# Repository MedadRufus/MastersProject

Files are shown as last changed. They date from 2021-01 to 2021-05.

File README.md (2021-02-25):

# MastersProject
 
# Requirements
Design a data logger for E bikes that can record:

It needs to 
* measure: battery current for output and charging(1mA precision), voltage(10mV precision), inclination of road, humidity(as proxy for rain), tempreature of battery, external temperature, e-bike velocity, accleration.
* run off the battery pack
* consume minimal power
* be sturdy enough to survive near the battery pack
* Measure the environmental values(temperature, humidity) without being affected by the system(e.g. heat from the battery)
* measure at least 2 weeks of non stop data
* option to auto upload to the cloud, when connected to wifi.
* cloud dashboard
* log data at max data rate of 1 sample per second
* Needs to handle significant noise in power supply generated by Motor
* Need to handle inductive currents from motor
* Needs isolation from motor.

The idea is to see how estimate battery discharge profiles to do accurate range and state of charge estimations.

Hardware ideas:
* Accleration/tilt from LSM9DS1. Tilt can be measured from sensor fusino on the mcu
* Processor: ESP32
* Current sensor: INA226, 500 kHz +/- 30% sample rate. Up to 36V.
* GPS: Ublox with antenna

# Overall System diagram


# Basic physical design
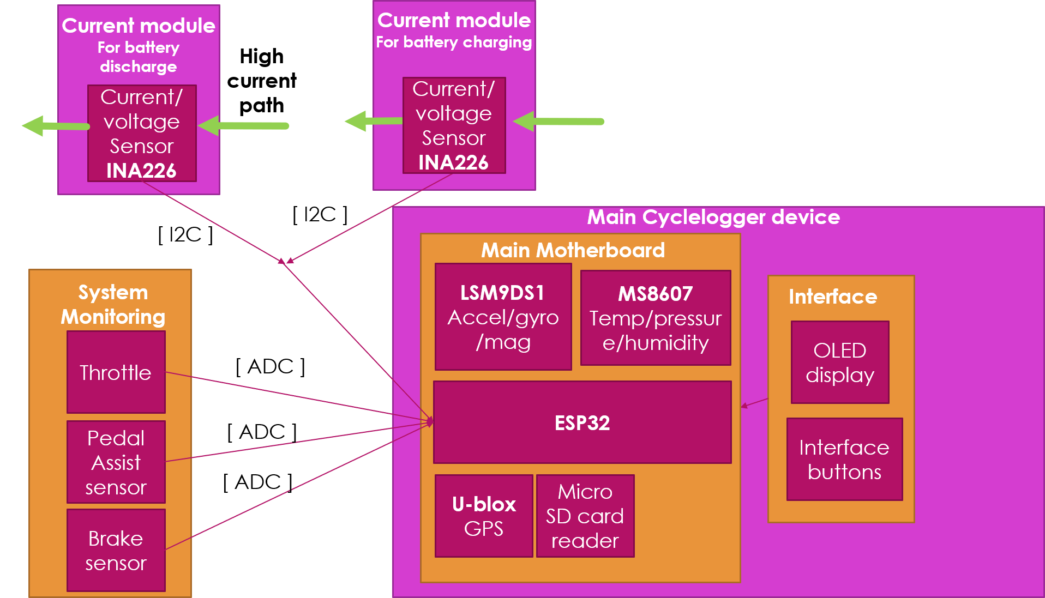
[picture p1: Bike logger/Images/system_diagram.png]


# Uses of sensor variables



# Software development

The following commands must be run as workarounds on the eBike Blackbox.

## How to disable strapping pin function of the MTDI pin(IO12)

On the PCB, the MTDI pin, IO12, is connected to the SD card MISO pin. In order to boot up, IO12 must be held low. Otherwise, it will brownout. 

Some explanation can be found on the [documentation](https://github.com/espressif/esptool/wiki/ESP32-Boot-Mode-Selection#other-pins).
```
If driven High, flash voltage (VDD_SDIO) is 1.8V not default 3.3V. Has internal pull-down, so unconnected = Low = 3.3V. May prevent flashing and/or booting if 3.3V flash is used and this pin is pulled high, causing the flash to brownout. See the ESP32 datasheet for more details.
```

Unfortunately, when SD card is inserted, MISO pin gets pulled up, causing continuous resets(boot loop).

So to disable this strapping function, we need to set the efuses to disable its functionality. 

So we need to install esptool. On windows 10, using conda terminal, run:
```bash
pip install esptool
```
Then run the following command to actually set the fuses. Set the `-p` argument to the port your esp32 is connected to.
```bash
python -m espefuse set_flash_voltage 3.3V -p COM6
```

You should be done now!

References:  
[https://www.esp32.com/viewtopic.php?t=5970](https://www.esp32.com/viewtopic.php?t=5970)  
[https://forum.micropython.org/viewtopic.php?t=4387#p25381](https://forum.micropython.org/viewtopic.php?t=4387#p25381)

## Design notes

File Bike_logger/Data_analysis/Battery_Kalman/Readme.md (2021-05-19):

A simple and naive battery modelisation + Kalman filter for state of charge (SoC) estimation

# Python implementation
The "Python" folder contain a python3 implementation of an extended Kalman filter for state of charge (SoC) estimation of a simulated lithium battery. The model used for the battery is a simple Thevenin model.

To run it just launch:
```sh
$> python3 main.py
```

A CC/CV charge and a pulse discharge will be simulated. Then a graph will be displayed showing simulation results. You can play around with the capacity and Thevenin model values in Python/main.py. The charge/discharge protocol can also be changed, values are found in Python/protocol.py.

## Dependencies:
    - python3
    - numpy
    - matplotlib

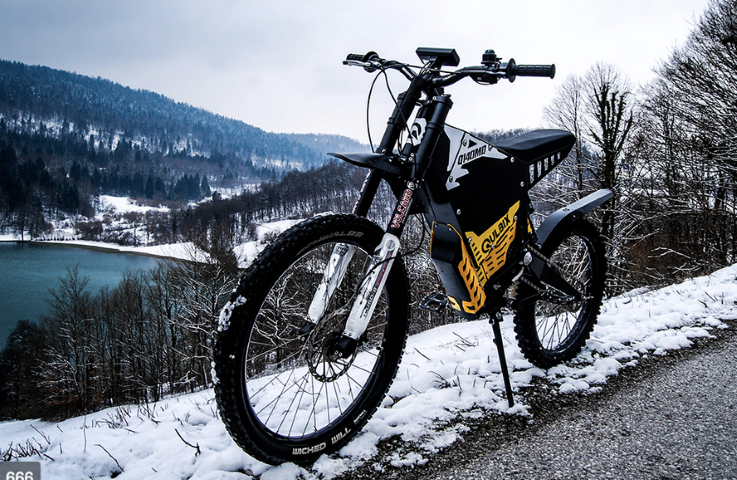
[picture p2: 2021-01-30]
Bike_logger/Images/Off_Road_Electric_Bike.png

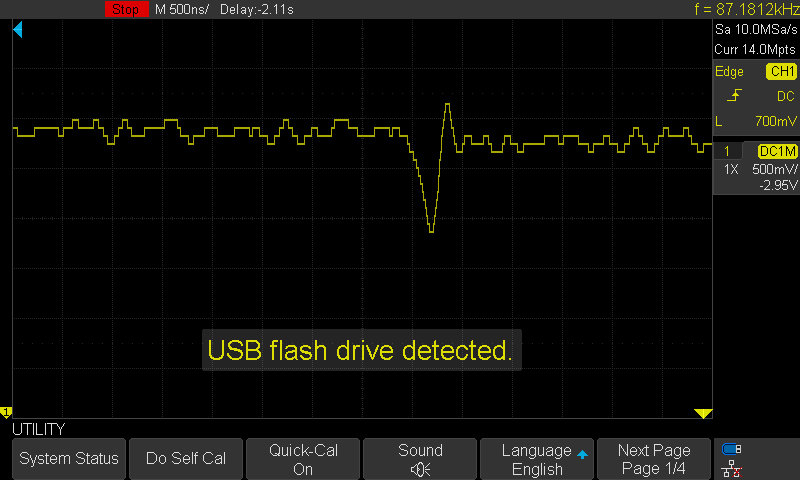
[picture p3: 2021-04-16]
Bike_logger/references/PNG/SDS00008.png

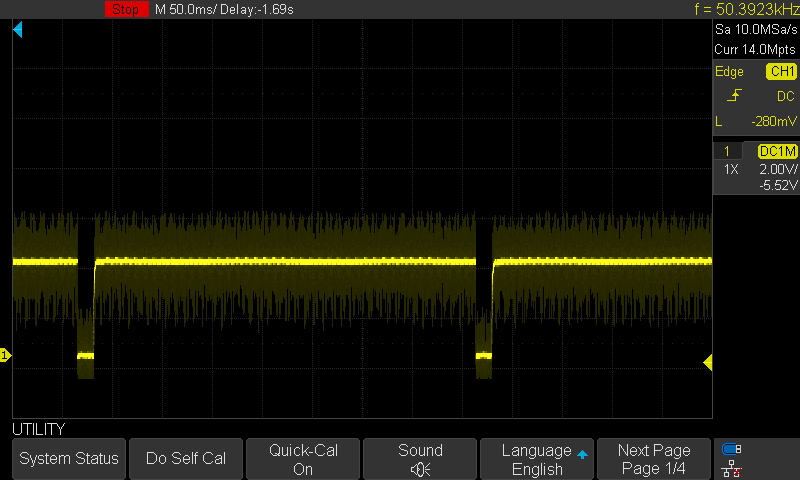
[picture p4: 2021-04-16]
Bike_logger/references/PNG/SDS00012.png

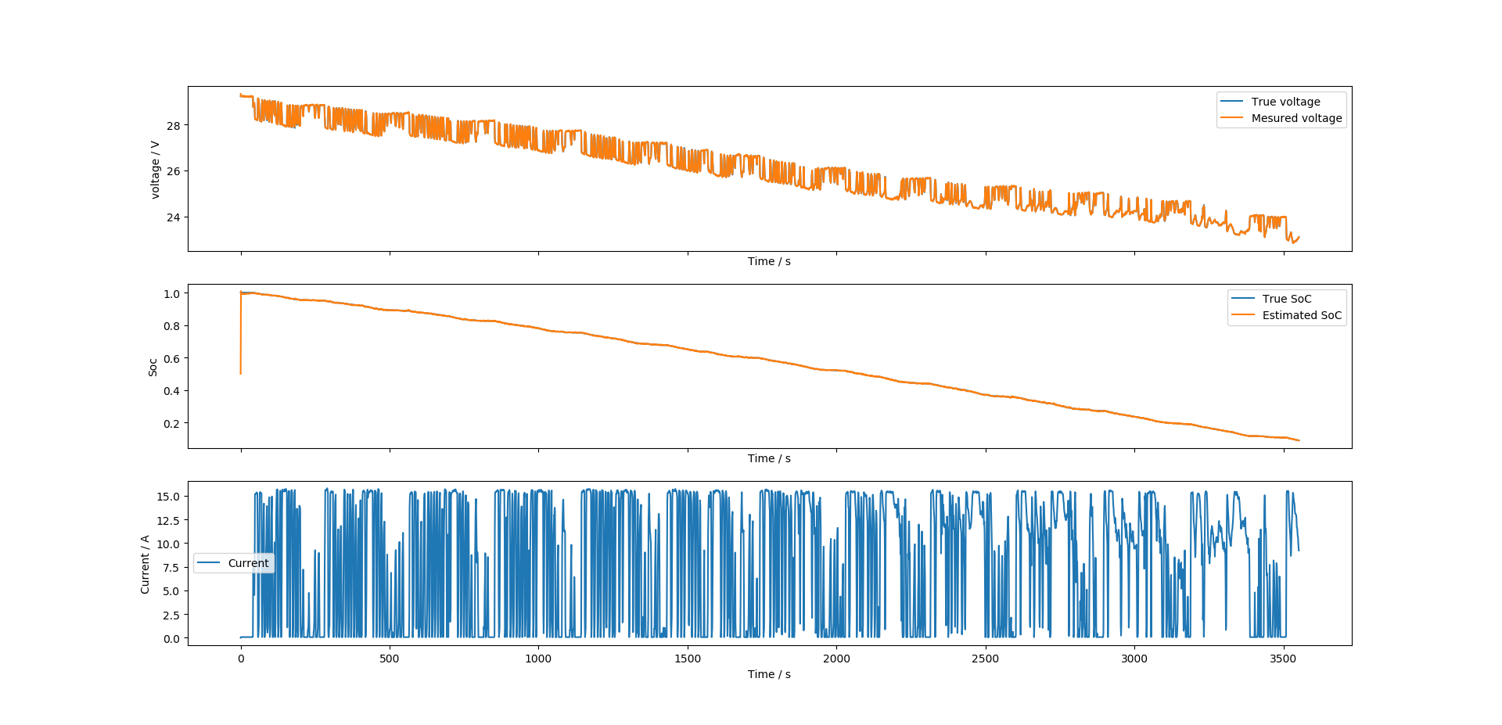
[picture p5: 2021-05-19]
Bike_logger/references/Discharge curve with real data.png

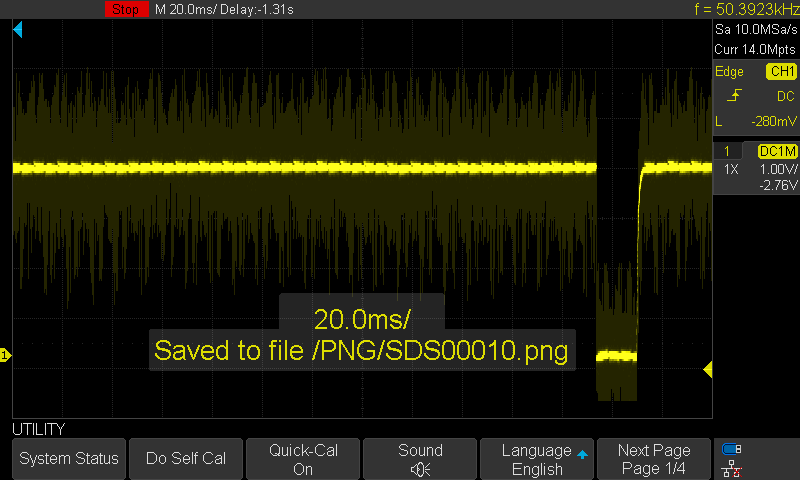
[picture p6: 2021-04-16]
Bike_logger/references/PNG/SDS00011.png

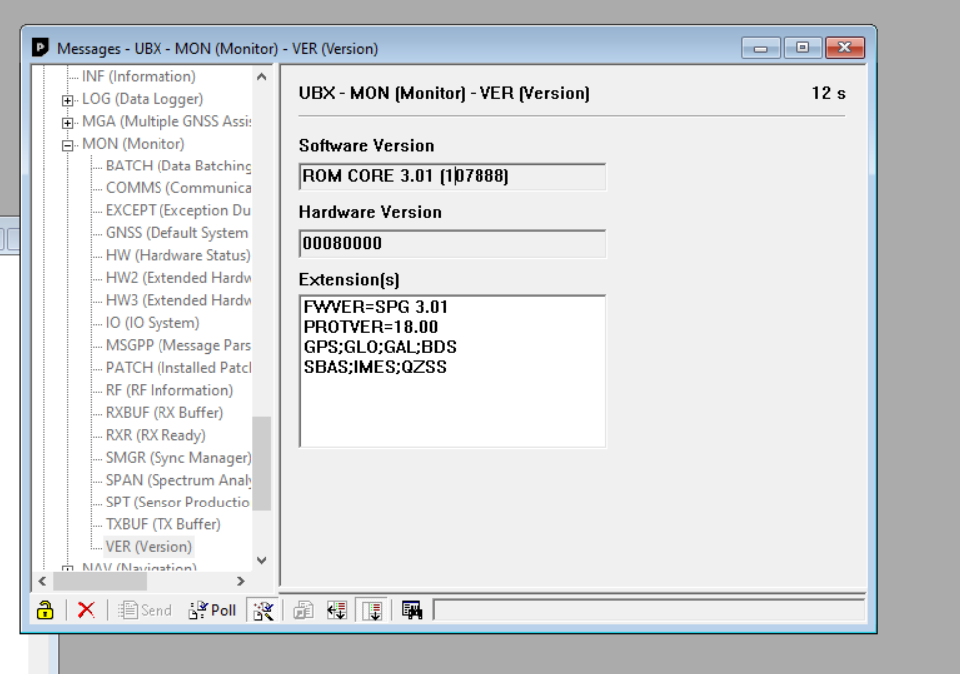
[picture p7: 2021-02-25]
Bike_logger/references/ublox gps version.PNG

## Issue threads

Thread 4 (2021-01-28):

select connectors for external components

MedadRufus, 2021-01-28:
This include

- [x] GPS
- [x] Throttle sensor
- [x] brake sensor
- [x] Pedal Assist sensor

Closed 2021-02-01.

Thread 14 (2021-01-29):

consider the possiblity that the current sense module is installed in reverse

MedadRufus, 2021-01-29:
When high side is connected to low side

MedadRufus, 2021-01-30:
not an issue for INA226

Closed 2021-01-30.

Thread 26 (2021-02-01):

Fix richard suggestions

MedadRufus, 2021-02-01:
- [x] add 100nF decoupling at SD Card socket
- [x] add 100nF decoupling at GPS connector
- [x] Add second grove connector with misc_adc raw_ 1 and 2 on it
- [x] make external I2C connector on IO18 and IO19, you can bus map to those pins and keep ADC on exiting connector if needed.
- [x] add decoupling for the external bus connectors
- [x] remove the ADC pins from the generic connector as now on grove. add a couple of grounds and 3.3V pin to connector so you can make useful connections. 5V might be useful too.
- [x] there are a lot of test points considering that you can probe the pins of the ESP32 at the edge like on the Ublox MAX module
- [x] C12 will need to be 100V working and will be physically larger because of this.
- [x] caps on sensors can be 100nF
- [x] add 100nF decoupling in parallel with C4
- [x] you have the display, but at least one LED might be reassuring.
- [x] Add pads for the trim resistors to the STH0548 regulator. Then you have some control over which supply takes priority.
- [ ] The ESP32 has DAC outputs on IO25 and IO26. Might be good to swap some pin to bring one of these to a connector?

Closed 2021-02-02.

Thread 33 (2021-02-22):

The 100V 10uF cap is the wrong way around

MedadRufus, 2021-02-22:
Polarity on PCB is wrong,

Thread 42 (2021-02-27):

wierd blips appear in the data.

MedadRufus, 2021-02-27:
Happens on ms8607, LSM6D. Could be I2C bus issue. Not sure. Maybe it happens when i2c bus reinits.

```
imu: -0.683688,-0.068320,0.733464,0.910000,-3.780000,1.120000
imu: -0.684664,-0.068320,0.732976,1.330000,-3.640000,1.540000
imu: -0.688568,-0.065880,0.733952,0.560000,-4.060000,0.700000
imu: -0.683688,-0.067344,0.736392,0.910000,-3.990000,1.120000
imu: -0.687104,-0.065392,0.741272,0.980000,-4.060000,1.260000
imu: -0.685640,-0.069296,0.737856,0.770000,-4.200000,1.050000
imu: -0.689056,-0.058072,0.730536,0.280000,-3.570000,0.700000
imu: -0.688568,-0.070272,0.736880,1.190000,-3.570000,1.400000
imu: -0.683200,-0.061488,0.743712,0.910000,-3.360000,1.050000
imu: -0.683688,-0.067344,0.737368,0.910000,-3.990000,1.190000
imu: -0.689056,-0.069296,0.738832,0.840000,-3.850000,1.120000
imu: -0.683200,-0.065392,0.732976,1.120000,-4.340000,1.260000
imu: -0.684176,-0.062464,0.733464,0.980000,-4.200000,1.190000
imu: -0.685152,-0.066856,0.735904,1.050000,-3.920000,1.330000
imu: -0.684664,-0.065880,0.733464,0.910000,-3.780000,1.050000
imu: -0.681248,-0.068808,0.737368,0.980000,-3.850000,1.190000
imu: -0.680760,-0.064904,0.733464,1.330000,-3.640000,1.470000
imu: -0.694424,-0.067832,0.724680,1.190000,-3.710000,1.470000
imu: -0.687104,-0.064416,0.735416,1.190000,-3.710000,1.330000
imu: -0.682712,-0.063440,0.732000,1.540000,-3.640000,1.750000
imu: -0.692472,-0.060512,0.746640,1.330000,-3.850000,1.540000
imu: -0.676368,-0.062952,0.737856,1.120000,-1.680000,1.470000
imu: -0.685640,-0.057584,0.733952,1.190000,-4.550000,1.470000
imu: -0.676856,-0.065392,0.732976,0.770000,-4.130000,1.050000
imu: -0.683688,-0.060024,0.744200,0.700000,-4.060000,0.910000
imu: -0.682224,-0.063440,0.726632,1.190000,-3.640000,1.260000
imu: -0.687104,-0.066856,0.738344,0.910000,-4.340000,1.050000
imu: -0.685152,-0.067344,0.742248,1.050000,-3.710000,1.330000
imu: -0.685152,-0.068808,0.739808,0.840000,-3.850000,1.050000
imu: -0.682712,-0.066368,0.738344,0.910000,-4.130000,1.050000
imu: -0.682712,-0.066856,0.741760,0.910000,-3.990000,1.050000
imu: -0.684176,-0.065392,0.739808,1.050000,-3.920000,1.260000
imu: -0.687592,-0.069296,0.738344,0.910000,-3.920000,1.190000
imu: -0.682224,-0.067832,0.753472,0.700000,-3.640000,0.840000
imu: -0.683688,-0.067832,0.732000,1.260000,-3.500000,1.400000
imu: -0.673928,-0.059536,0.743224,1.470000,-4.340000,1.750000
imu: -0.689544,-0.076616,0.743712,1.330000,-3.780000,1.680000
imu: -0.686616,-0.072224,0.734928,0.700000,-4.690000,0.910000
imu: -0.675880,-0.059048,0.723704,0.630000,-4.620000,0.630000
imu: -0.676368,-0.066368,0.738344,1.190000,-3.640000,1.190000
imu: -0.679784,-0.064904,0.737856,1.470000,-4.270000,1.400000
imu: -0.684664,-0.062952,0.739320,0.980000,-4.060000,0.910000
imu: -0.674904,-0.065392,0.736392,1.750000,-4.340000,1.820000
imu: -0.682712,-0.068320,0.742248,1.050000,-3.570000,1.260000
imu: -0.671488,-0.051240,0.736392,1.260000,-2.940000,1.820000
imu: -0.690032,-0.062952,0.745176,0.350000,-3.920000,0.700000
imu: -0.683200,-0.061976,0.742736,0.980000,-3.920000,0.980000
imu: -0.681248,-0.061976,0.728096,0.630000,-4.200000,0.840000
imu: -0.677832,-0.068320,0.738832,0.630000,-3.710000,0.770000
imu: -0.681736,-0.065392,0.735904,0.770000,-3.920000,1.120000
imu: -0.682224,-0.065392,0.740296,0.700000,-3.920000,0.980000
imu: -0.674904,-0.066368,0.733952,1.120000,-3.360000,1.470000
imu: -0.695888,-0.072224,0.735904,0.770000,-4.550000,1.120000
imu: -0.680760,-0.064416,0.734440,0.980000,-4.130000,1.120000
imu: -0.680272,-0.064416,0.736880,1.050000,-4.200000,1.190000
imu: -0.681736,-0.064416,0.739320,1.120000,-4.060000,1.050000
imu: -0.683200,-0.065880,0.731024,0.980000,-4.060000,1.260000
imu: -0.680272,-0.059536,0.737368,0.770000,-4.200000,0.910000
imu: -0.682224,-0.066368,0.734928,0.840000,-4.060000,1.190000
imu: -0.679784,-0.066856,0.732488,1.680000,-3.710000,1.820000
imu: -0.682712,-0.064416,0.738832,0.910000,-4.200000,0.980000
imu: -0.684664,-0.062952,0.734928,1.050000,-3.360000,1.330000
imu: -0.683688,-0.067344,0.735904,0.770000,-3.780000,0.910000
imu: -0.677832,-0.063440,0.736880,1.050000,-4.410000,1.050000
imu: -0.683688,-0.062952,0.732976,0.770000,-3.920000,0.840000
imu: -0.684176,-0.067344,0.739320,0.630000,-3.850000,0.840000
imu: -0.681248,-0.063928,0.739320,0.980000,-3.640000,1.190000
imu: -0.681248,-0.065880,0.736392,0.910000,-4.130000,1.190000
imu: -0.679296,-0.066368,0.739320,0.910000,-3.850000,1.260000
imu: -0.678808,-0.065392,0.741272,1.050000,-3.640000,1.190000
imu: -0.683200,-0.066368,0.736880,0.840000,-4.060000,1.050000
imu: 15.363216,15.363216,0.736880,1.050000,-3.850000,1.190000
imu: -0.686616,-0.066856,0.741272,0.910000,-3.850000,1.190000
imu: -0.683200,-0.067344,0.736392,0.840000,-3.990000,1.120000
imu: -0.683200,-0.063928,0.738832,0.980000,-4.060000,1.190000
imu: -0.679784,-0.068808,0.737856,1.120000,-4.130000,1.260000
imu: -0.683688,-0.065392,0.739320,0.910000,-3.990000,1.120000
imu: -0.680272,-0.067832,0.741272,0.910000,-4.340000,1.050000
imu: -0.678320,-0.064416,0.746640,1.050000,-4.060000,1.400000
imu: -0.680760,-0.066368,0.732488,1.120000,-3.920000,1.190000
imu: -0.685152,-0.063440,0.737368,0.910000,-3.710000,1.190000
imu: -0.688568,-0.063440,0.734928,0.420000,-2.520000,0.700000
imu: -0.687104,-0.105408,0.734440,3.080000,-5.110000,3.290000
imu: -0.700768,-0.084912,0.739808,-0.910000,-5.320000,0.000000
imu: -0.678320,-0.062464,0.728584,3.360000,-4.760000,2.730000
imu: -0.688568,-0.066856,0.728096,1.050000,-2.800000,1.330000
imu: -0.663192,-0.055632,0.724680,1.750000,-4.830000,1.470000
imu: -0.687592,-0.071248,0.741272,-0.210000,-4.690000,-0.140000
imu: -0.700280,-0.071736,0.717848,0.560000,-3.220000,0.350000
imu: -0.676368,-0.054168,0.746640,0.910000,-3.640000,1.190000
imu: -0.663680,-0.058072,0.743712,1.610000,-4.550000,1.540000
imu: -0.670512,-0.066856,0.741760,0.980000,-4.060000,1.330000
imu: -0.677832,-0.061976,0.744200,0.910000,-2.940000,1.190000
imu: -0.683688,-0.061488,0.742736,0.700000,-4.270000,0.980000
imu: -0.685640,-0.067832,0.745664,1.260000,-3.850000,1.540000
imu: -0.678808,-0.061976,0.742736,0.420000,-3.570000,0.980000
imu: -0.649528,-0.050752,0.724680,-0.070000,-1.960000,1.750000
imu: -0.658312,-0.027816,0.671488,0.630000,-1.610000,2.240000
imu: -0.689056,-0.089304,0.740784,-0.980000,1.330000,2.030000
imu: -0.727608,-0.073688,0.751520,-0.350000,-3.640000,-0.070000
imu: -0.691984,-0.069784,0.743712,1.610000,-3.920000,1.120000
imu: -0.694424,-0.071736,0.733952,1.540000,-4.970000,1.330000
imu: -0.680760,-0.070760,0.740784,0.210000,-3.850000,0.350000
imu: -0.680760,-0.066856,0.736392,1.960000,-4.130000,1.610000
imu: -0.689056,-0.072224,0.737368,0.770000,-3.290000,1.120000
```

MedadRufus, 2021-02-27:
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
Graphical representation

MedadRufus, 2021-03-01:
Could be the I2C pullups are not strong enough. Replace the 10k pullups with 1k

MedadRufus, 2021-03-08:
not related to pull up. Some data simply goes missing

MedadRufus, 2021-04-08:
It could be that the i2c address occasionally changes, because the LSB set pin is left floating. Thats why we occasionally see missing data. Workaround is to set it set high via internal pullup. It can be done by setting register.
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

Closed 2021-05-05.

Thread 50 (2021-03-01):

Sample second INA226

MedadRufus, 2021-03-01:

MedadRufus, 2021-03-01:
fixed in #52

Closed 2021-03-01.

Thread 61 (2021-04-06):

Put in pullup resistors on SPI bus to sd card.

MedadRufus, 2021-04-06:
Quoting from the documentation:
```
SD pull-up requirements apply to cases where ESP32 uses the SPI controller to communicate with SD cards. When an SD card is operating in SPI mode or 1-bit SD mode, the CMD and DATA (DAT0 - DAT3) lines of the SD bus must be pulled up by 10 kOhm resistors. Slaves should also have pull-ups on all above-mentioned lines (regardless of whether these lines are connected to the host) in order to prevent SD cards from entering a wrong state.
```

Source: https://docs.espressif.com/projects/esp-idf/en/v4.2/esp32/api-reference/peripherals/sd_pullup_requirements.html

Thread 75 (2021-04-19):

Upsample all variables so that all have the same sample rate.

MedadRufus, 2021-04-19:
So that we can run correlation algorithms/machine learning.

MedadRufus, 2021-04-19:
Use this? https://dsp.stackexchange.com/questions/8488/what-is-an-algorithm-to-re-sample-from-a-variable-rate-to-a-fixed-rate

MedadRufus, 2021-05-07:
just use merge asof, and use highest sample rate

Closed 2021-05-07.

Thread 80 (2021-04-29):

consider using time series ML

MedadRufus, 2021-04-29:
Using xgboost does not consider the time aspect at all. It only considers the patterns across each row. When voltage is this, power is this.

MedadRufus, 2021-05-18:
not very useful. Use an ML model that combines timeseries with row data

Closed 2021-05-18.

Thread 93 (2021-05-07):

Detect braking

MedadRufus, 2021-05-07:
ON the log, on neg edge, log high, then low(or vise versa) immediately so that the transitions and current state is logged

MedadRufus, 2021-05-07:
fixed in d49bb8af87c05773881853825d42825cd87abc29

Closed 2021-05-07.

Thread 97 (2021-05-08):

Plot voltage based SOC measurment vs Culumb counting based SOC measurment

MedadRufus, 2021-05-08:
Show them side by side, and show how instantaneous changes in voltage confuses the whole thing. Then show a demo when a Low pass filter is applied to voltage, and how SOC reacts.

MedadRufus, 2021-05-18:
duplicate of #114

Closed 2021-05-18.

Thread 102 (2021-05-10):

Observation: When low batt, looks like less power is available

MedadRufus, 2021-05-10:
This can be seen over averaged data. Looks to me that it can only provide short bursts when low on power, hence less overall power.

Closed 2021-05-18.

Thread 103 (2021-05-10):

Estimate rider effort from difference in power over same slope, speed

MedadRufus, 2021-05-10:
Assuming same slope and speed, the power output to the wheels should be the same. Therefore variations in power output from the battery can be explained by more or less rider effort.

Closed 2021-05-18.

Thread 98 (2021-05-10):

Don't bother with soc of battery. Use maximum usable power

MedadRufus, 2021-05-10:
We can find the full state(charger stops charging), we can find the empty state, 0% SOC when bike does not turn on. So now we know the full usable power, by integrating the power with time with the full discharge.

Closed 2021-05-26.

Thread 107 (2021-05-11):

Estimating power consumption is hard due to accumulation errors

MedadRufus, 2021-05-11:
The longer the estimated period, the more accumulated error. The way to solve this is to do fixed predictions of n minutes, like a sliding rule across ALL the data we have. Each dataset is for example 1-10th minute, 2nd to 12th minute, 3rd to 13th minute, to estimate power consumption over that period.

MedadRufus, 2021-05-18:
written in report

Closed 2021-05-18.

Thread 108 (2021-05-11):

There are quite high frictional forces even when coasting

MedadRufus, 2021-05-11:
Possibly due to the motor, which explains slowing down even on downslope

MedadRufus, 2021-05-18:
combining with another issue

Closed 2021-05-18.

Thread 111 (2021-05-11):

Correlate Power (low passed or integrated) with acceleration/gyro

MedadRufus, 2021-05-11:
I think riding on rough terrain consumes more power. Can we predict power consumption from vibration? If we know the terrain in advance, we can predict power. strategy: high sample rate acceleration, filter then down sample to power sample rate, to minimise losses in info

MedadRufus, 2021-05-11:
Consider classifying the terrains as rough vs smooth

MedadRufus, 2021-05-18:
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
Acceleration/Gyro not very important. Although not low passed in this plot.

Closed 2021-05-18.

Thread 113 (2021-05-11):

Wierd timeline for imu

MedadRufus, 2021-05-11:
This is the culprit:
```
2021,imu,0.834480,-0.284992,0.833992,14.770000,-3.990000,2.310000
```

For some reason, the date is not present.

MedadRufus, 2021-05-12:
Ok filter out malformed timestamps out

Closed 2021-05-12.

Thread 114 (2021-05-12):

Do side by side comparison of SOC estimation methods

MedadRufus, 2021-05-12:
Compare voltage based, Culoumb counting and kalman filter(matlab)

MedadRufus, 2021-05-15:
This website has very good resources on that.

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

MedadRufus, 2021-05-15:
This is a good resource on using kalman filters: https://www.jackogrady.me/battery-management-system/state-of-charge
The plots are good.

MedadRufus, 2021-05-18:
Show them side by side, and show how instantaneous changes in voltage confuses the whole thing. Then show a demo when a Low pass filter is applied to voltage, and how SOC reacts.

Closed 2021-05-26.

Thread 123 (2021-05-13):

Create plots of distributions of all the data features

MedadRufus, 2021-05-13:
Consider making aggregated plots of the energy profiles similar to figure 13

We want the model and data to look the same.
https://www.sciencedirect.com/science/article/pii/S0360319914007393

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

MedadRufus, 2021-05-13:
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

MedadRufus, 2021-05-13:
Show commulated energy usage in a trip.

Closed 2021-05-26.

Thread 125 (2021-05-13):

Calibrate Baro Altitude with GPS altitude on every trip/ or 20 minute interval

MedadRufus, 2021-05-13:
The offset error changes in 1-2 hours.

Closed 2021-05-26.

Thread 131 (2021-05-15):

Use kalman filter to smooth out power output

MedadRufus, 2021-05-15:

MedadRufus, 2021-05-18:
Not necessary. Let the ML model handle the noise by itself. Dont info by filtering

Closed 2021-05-18.

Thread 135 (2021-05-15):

Latitude could be a strong indicator of power, since at certain locations, motor kicks in

MedadRufus, 2021-05-15:
This can been seen on the putney loop plots.
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

MedadRufus, 2021-05-18:
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

When binning in 1 second intervals, it can be seen that the locations where no power is supplied to the motor are almost exactly at the same place on each loop. We also see consistancy in power consumption on the west upslope, when the power is on throughout. On the downslope on the east, the power consumption is minimised. On the flat section, marked by the highlighter circles, the motor kicks in and out, almost at the same locations each time.

Closed 2021-06-01.

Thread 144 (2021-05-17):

Train the model to predict energy usage over a stretch rather than power

MedadRufus, 2021-05-17:
Use a neural net for regression. The input should be short 10 second n dimensional inputs, containing all the interesting features. The output should be the energy consumed on section.

Closed 2021-05-26.

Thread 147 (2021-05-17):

Find out what the real motor drag coefficient

MedadRufus, 2021-05-17:
Combine slope, mass and regions with no braking/pedaling in the data. Use F=ma

MedadRufus, 2021-05-17:
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
Source: https://www.mdpi.com/1996-1073/10/5/608/htm

 A Data-Driven Method for Energy Consumption Prediction and Energy-Efficient Routing of Electric Vehicles in Real-World Conditions
by Cedric De Cauwer
1,*, Wouter Verbeke
1, Thierry Coosemans
1, Saphir Faid
2 and Joeri Van Mierlo
1 [OrcID]

MedadRufus, 2021-05-17:
Energy sources: Motor(known), Human Effort(Unknown, related to pedaling rate), Brake losses(applies only when brake applied)

MedadRufus, 2021-05-18:
Combine with #108

MedadRufus, 2021-05-18:
Estimate rider effort from difference in power over same slope, speed.
Assuming same slope and speed, the power output to the wheels should be the same. Therefore variations in power output from the battery can be explained by more or less rider effort.

MedadRufus, 2021-05-26:
Dont bother. Use pure ML

MedadRufus, 2021-05-26:
No need to use model method

Closed 2021-05-26.

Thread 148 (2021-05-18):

Calculate SOC as a function of {Voltage, Current}

MedadRufus, 2021-05-18:
On solution is to train a ML. The ground truth SOC can be determined from Coulomb counting method, which is accurate when we know the things is in full SOC. Then train the model with voltage, current and output Coulomb Counting SOC

Closed 2021-05-18.

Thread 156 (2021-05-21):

Fix all the units on the plots

MedadRufus, 2021-05-21:
Most dont state units as milliamps/A

Closed 2021-06-01.

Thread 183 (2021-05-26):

Find out realistically, how high should the sample rate be to make predictions accurate.

MedadRufus, 2021-05-26:
My suspicions are, it is not necessary to sample at 100 Hz.

MedadRufus, 2021-05-26:
Downsampling to 10 Hz,  predictions are terrible.

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

Closed 2021-05-26.

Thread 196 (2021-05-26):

limited battery life is a pernial problem for EVs.

MedadRufus, 2021-05-26:
Intelligent decision making is requited to decide whether to make a trip via a certain route, or at all. The informed rider will have more confidence in riding, without worrying

Closed 2021-06-01.

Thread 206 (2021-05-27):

Calculate SOC with couloumb counting, but start SOC calculated with voltage lookup method

MedadRufus, 2021-05-27:
The ML approach seems to be introducing a lot of error. And I am not confident about the training amount. Its probably too little.

MedadRufus, 2021-05-27:
SOC reading at start of trip is usually accurate because it is 1. Open circuit, 2. Had a long relaxation period.

Closed 2021-06-01.

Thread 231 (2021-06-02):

Hypothesis: The model scales well with trip length

MedadRufus, 2021-06-02:
This is liekly because the short term over/underestimates cancel out to reflect the broader power profile along the route

MedadRufus, 2021-06-02:
Short term fluxtuations in power are caused by when the motor cuts in and out, but in the longer term, the proportion of time spent in high state and low state is more important.

MedadRufus, 2021-06-02:
The model struggles to predict the short term power fluxtuations, but has a good understanding of the long term power profile.

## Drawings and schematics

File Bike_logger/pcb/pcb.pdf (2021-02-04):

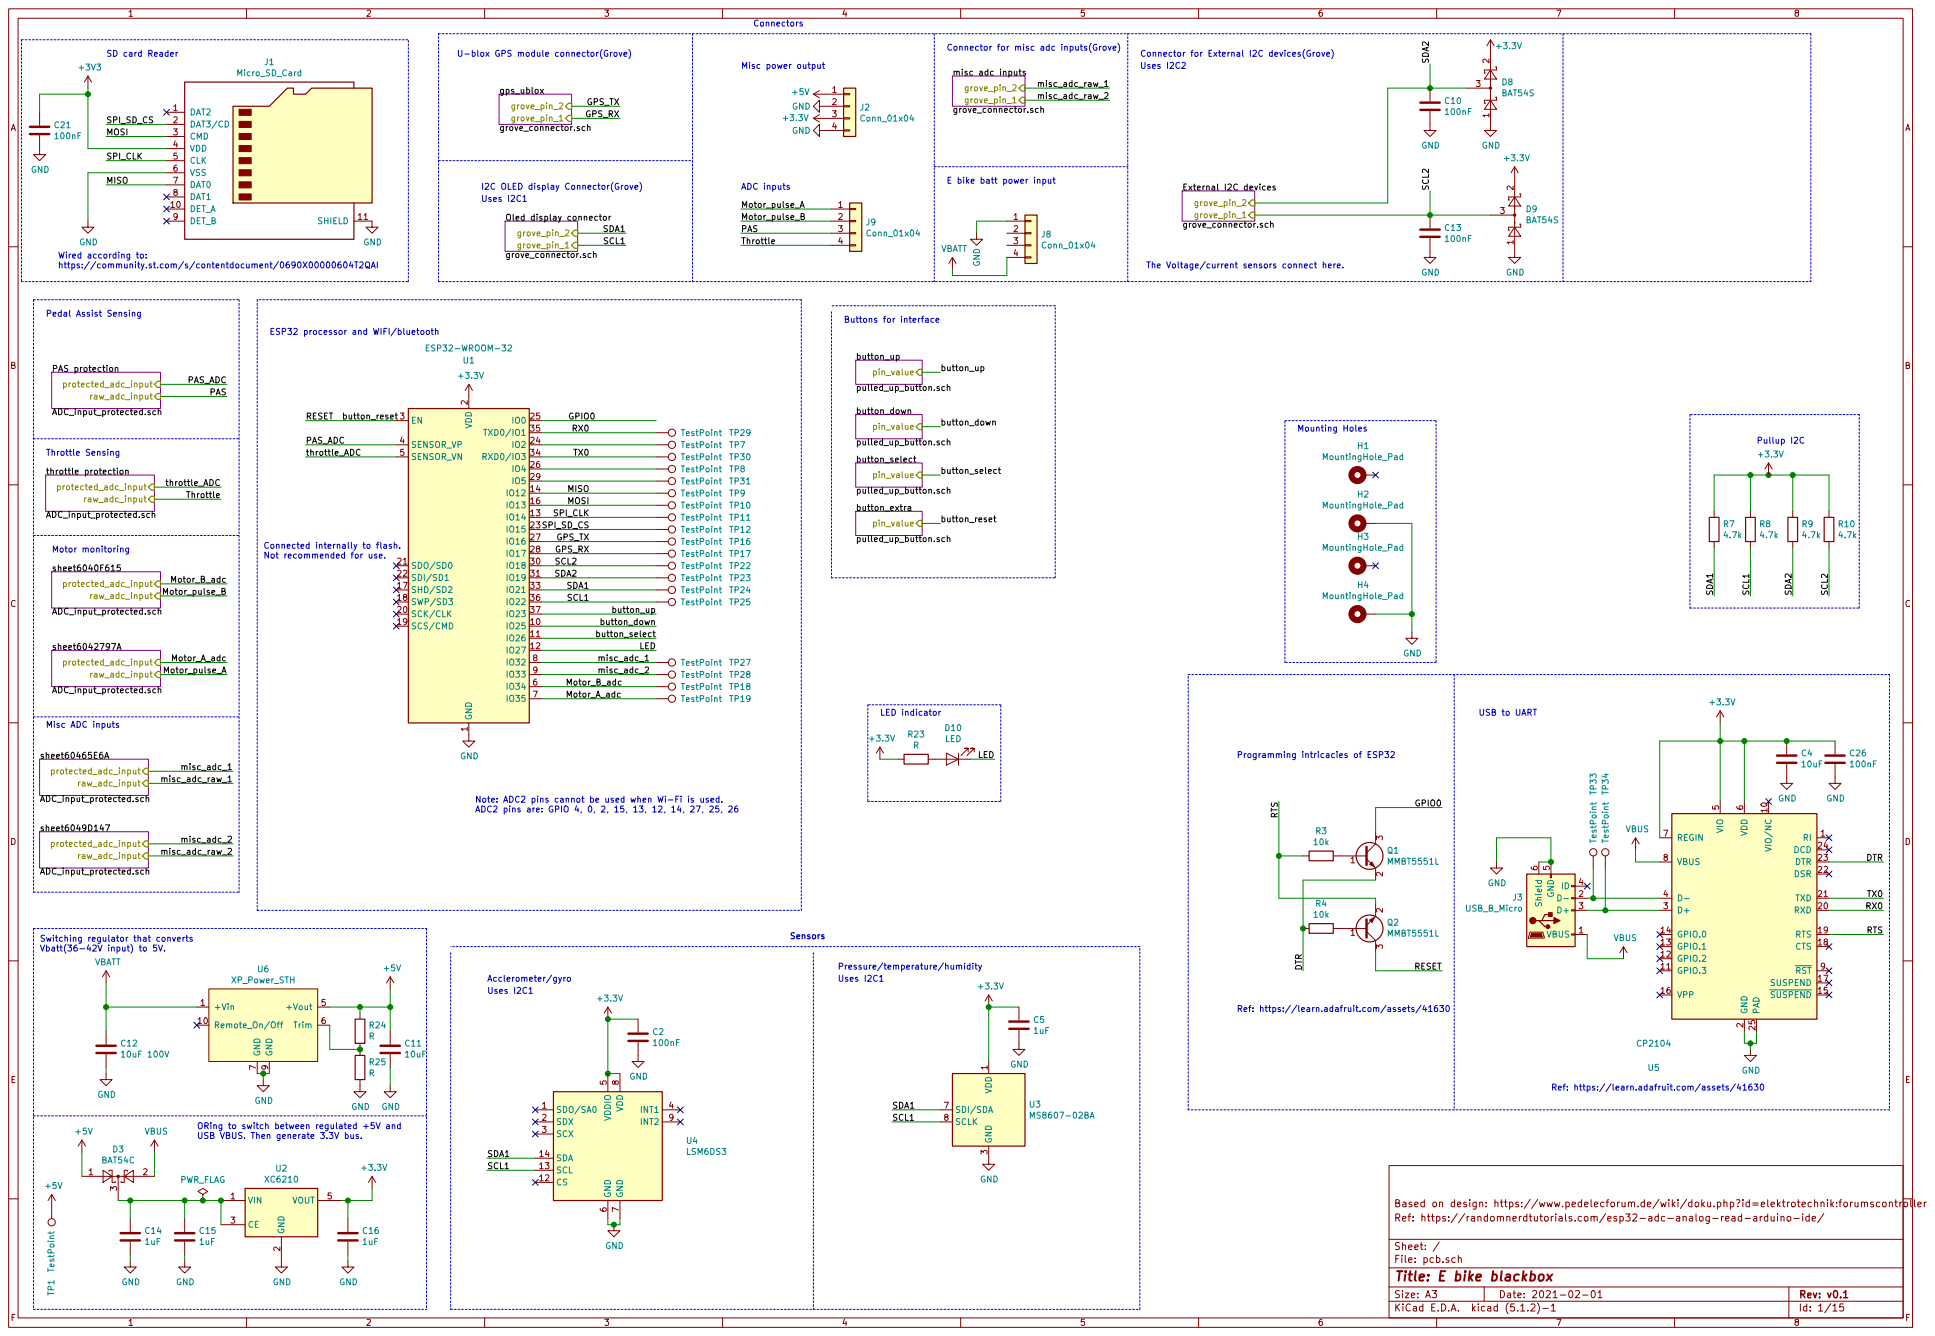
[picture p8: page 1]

Connector for misc adc inputs(Grove)

ESP32 processor and WIFI/bluetooth SD card Reader

Connector for External I2C devices(Grove)

E bike batt power input VBATT GND

https://community.st.com/s/contentdocument/0690X00000604T2QAI GND
Wired according to:

2 SCK/CLK 20 SDO/SD0 21 SDI/SD1 22

Note: ADC2 pins cannot be used when Wi-Fi is used.
ADC2 pins are: GPIO 4, 0, 2, 15, 13, 12, 14, 27, 25, 26

Switching regulator that converts Vbatt(36-42V input) to 5V. C12 VBATT +5V 10uF 100V | C11

Ref: https://learn.adafruit.com/assets/41630

Based on design: https://www.pedelecforum.de/wiki/doku.php?id=elektrotechnik:forumscontroller SCL1 SDA1

1uF GND ORing to switch between regulated +5V and

VBUS | USB VBUS. Then generate 3.3V bus.

File: pcb.sch Sheet: / Ref: https://randomnerdtutorials.com/esp32-adc-analog-read-arduino-ide/

Id: 1/15 Title: E bike blackbox

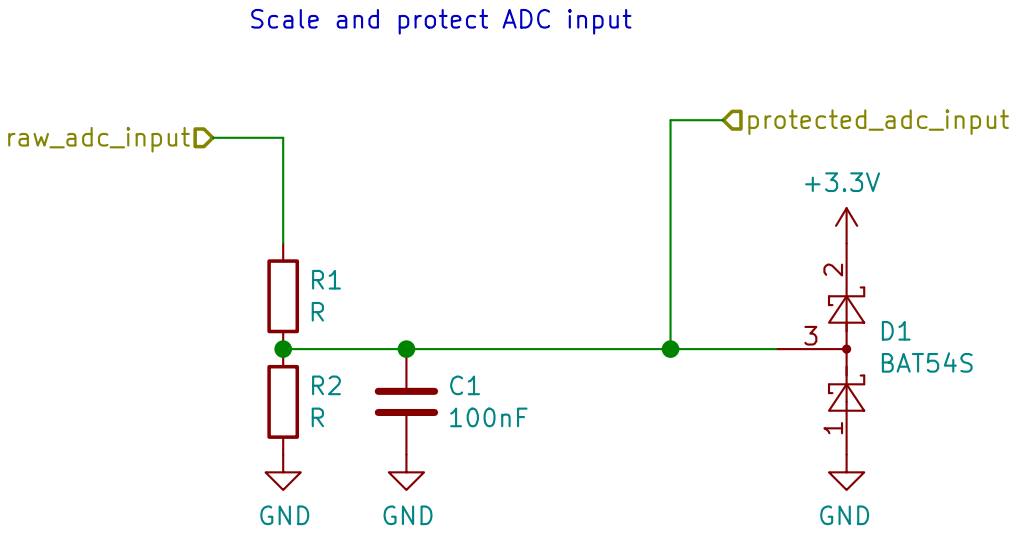
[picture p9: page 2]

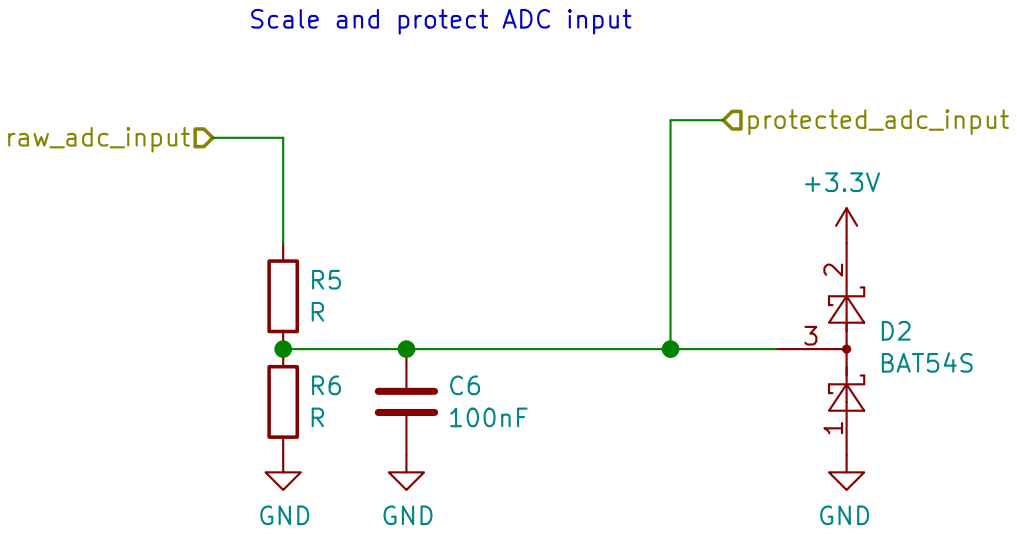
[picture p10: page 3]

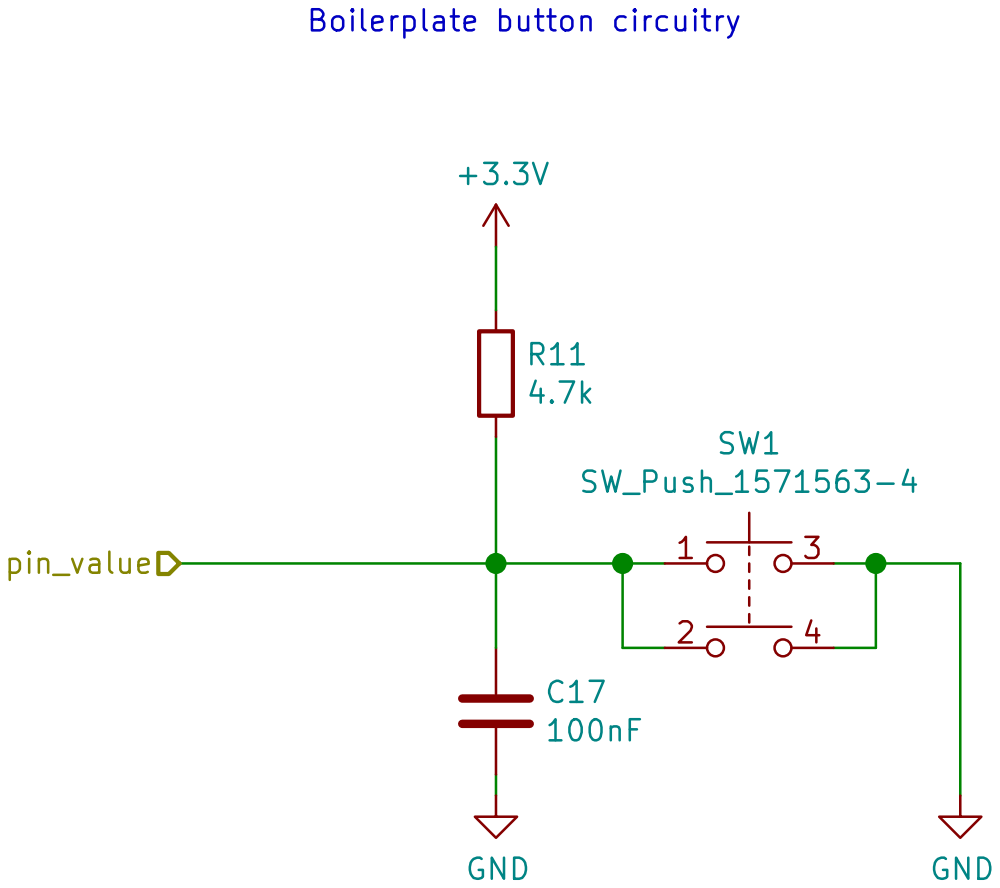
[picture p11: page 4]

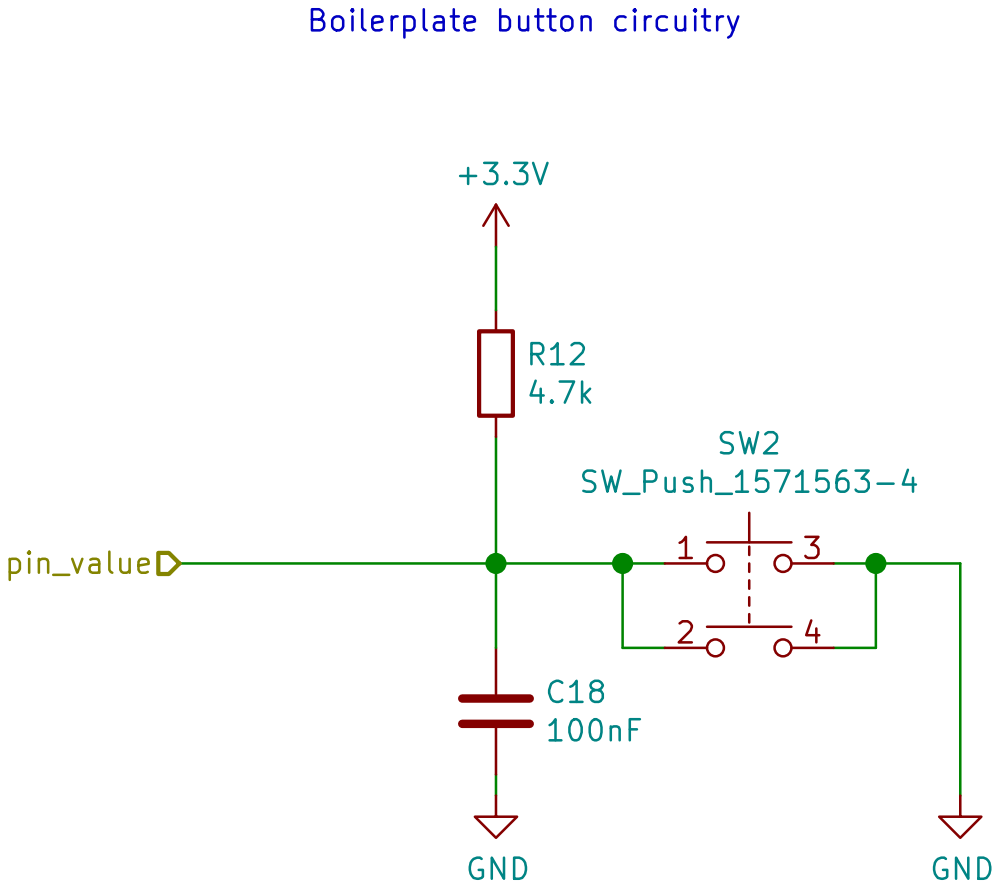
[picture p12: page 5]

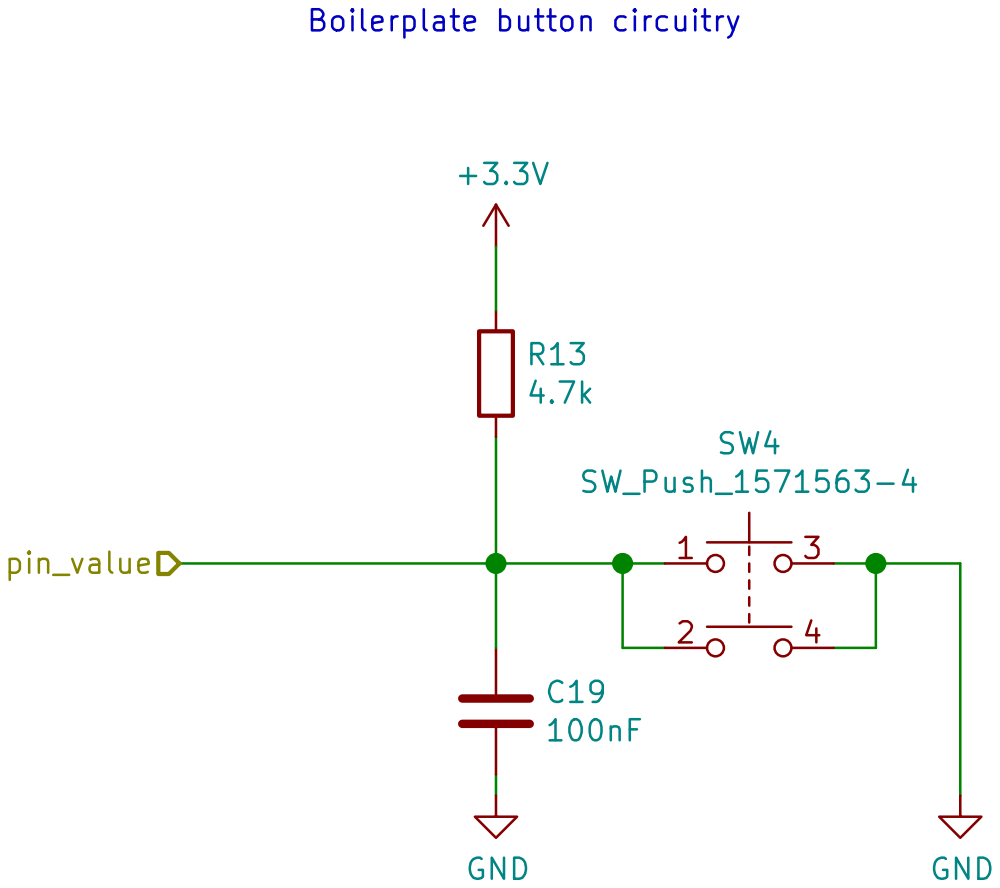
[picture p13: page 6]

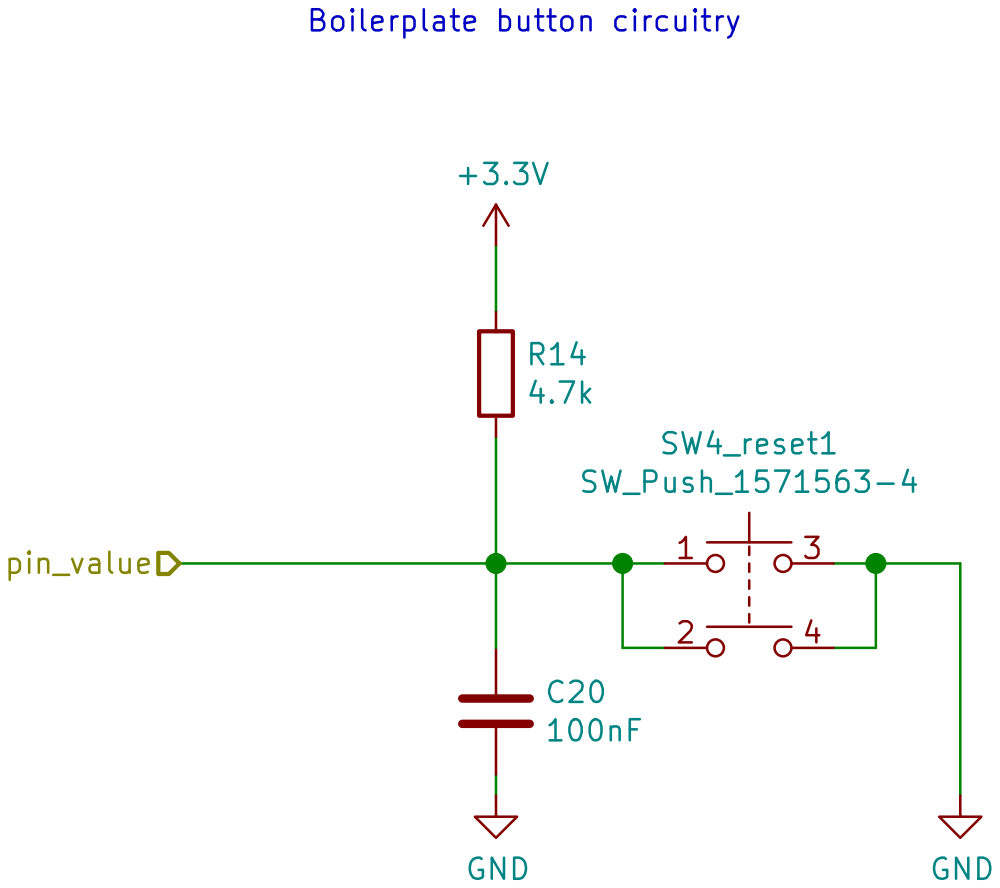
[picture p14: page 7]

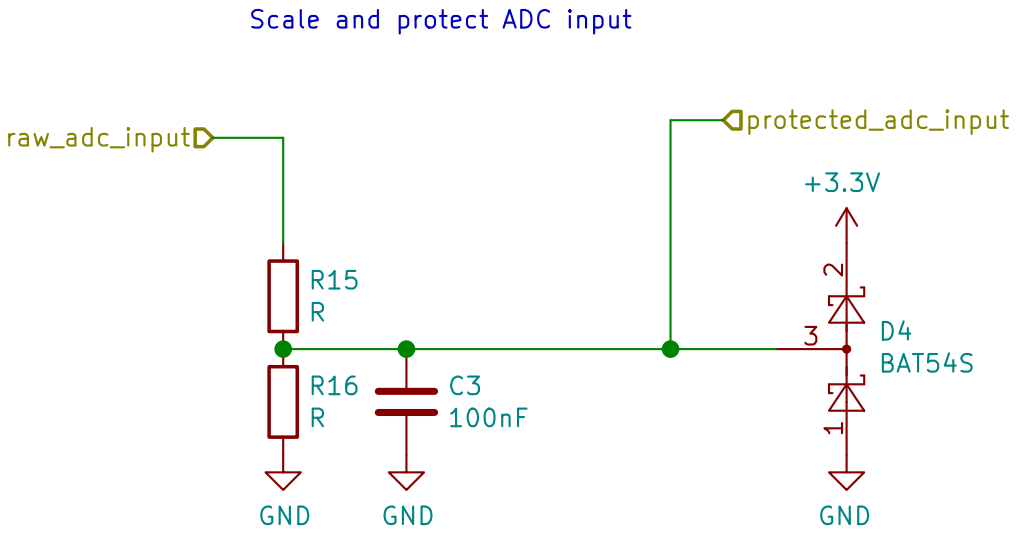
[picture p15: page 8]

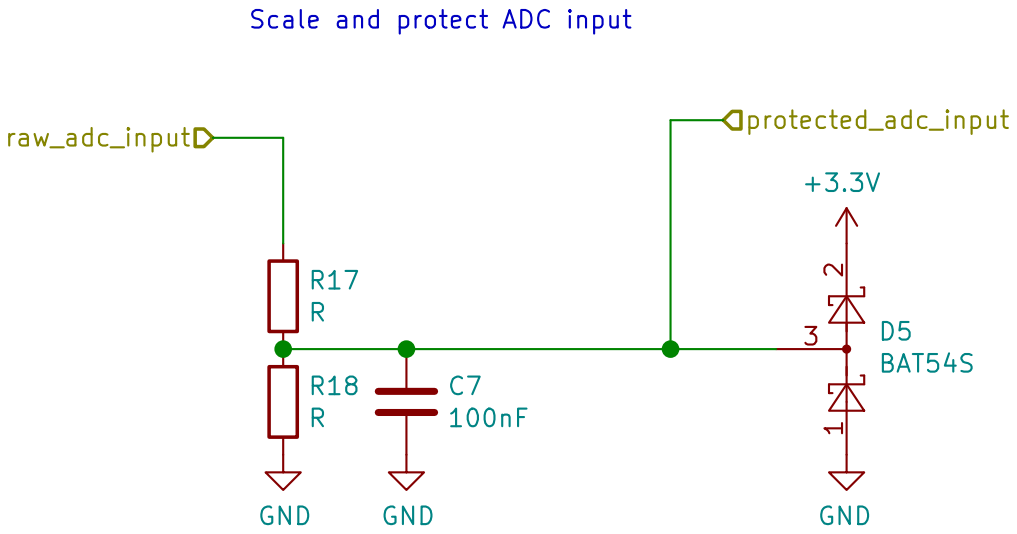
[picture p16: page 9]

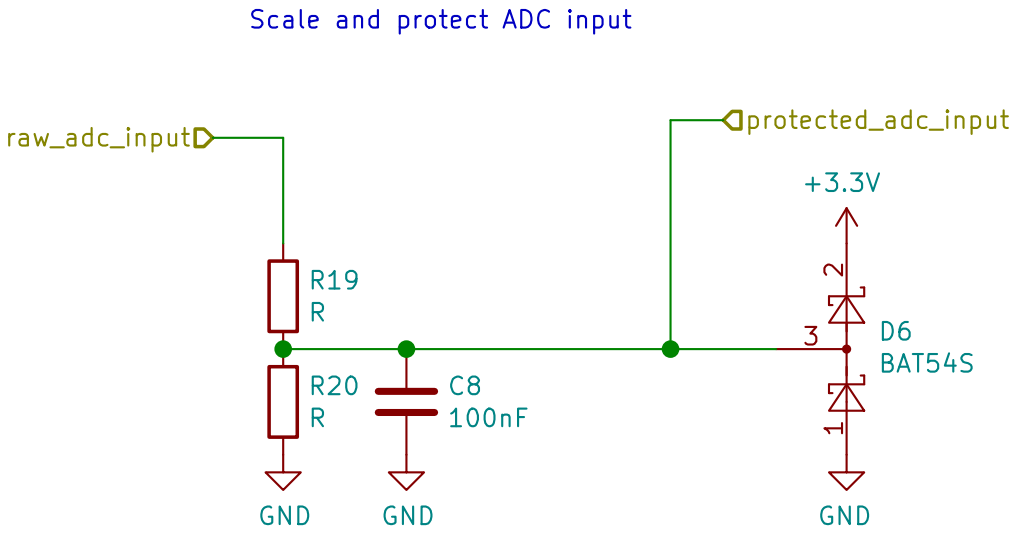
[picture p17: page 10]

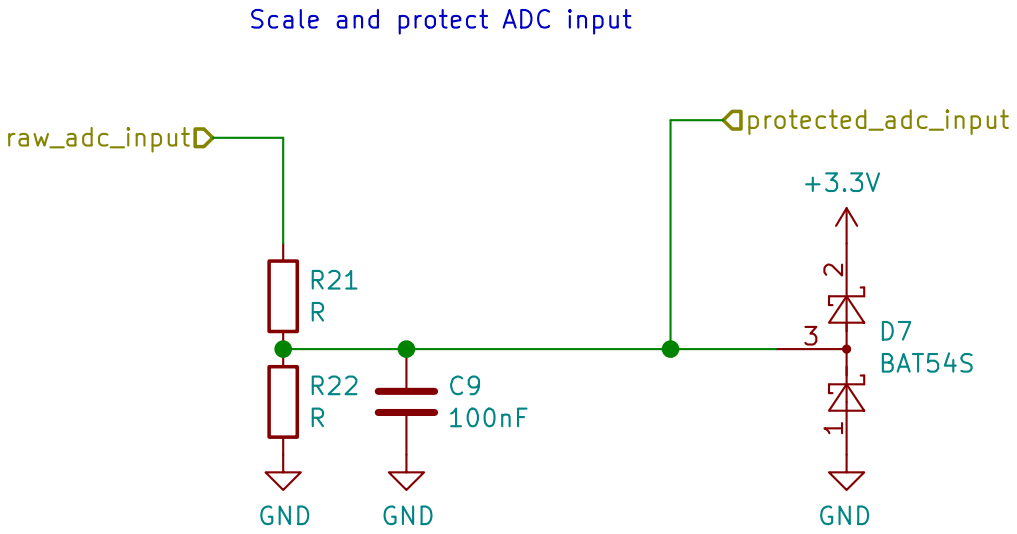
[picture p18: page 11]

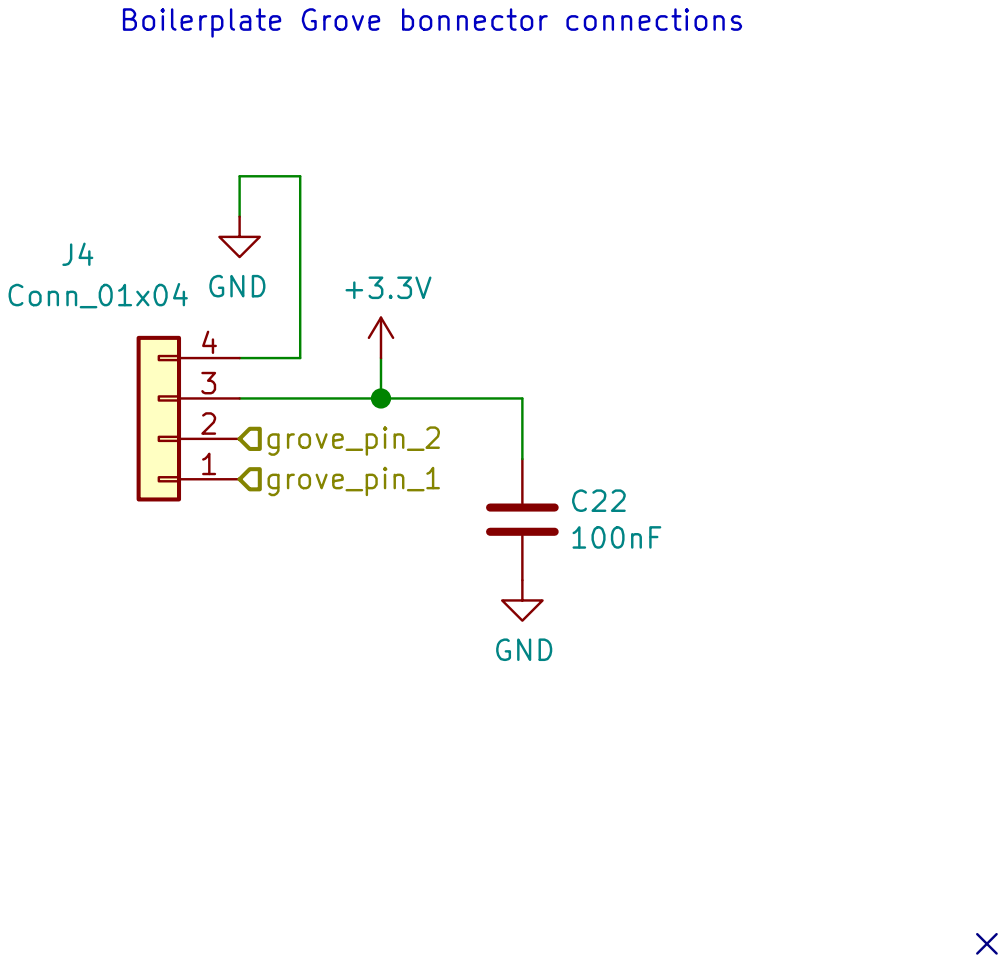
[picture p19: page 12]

Boilerplate Grove bonnector connections


Boilerplate Grove bonnector connections

Sheet: /Oled display connector/
File: grove_connector.sch
Id: 13/15 Title:


Boilerplate Grove bonnector connections

File: grove_connector.sch Sheet: /External I2C devices/
Id: 14/15 Title:


Boilerplate Grove bonnector connections

Sheet: /misc adc inputs/
File: grove_connector.sch
Id: 15/15 Title:

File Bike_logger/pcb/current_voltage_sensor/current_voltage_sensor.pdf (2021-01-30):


the analogue signal to a digital I2C signal.
File: current_voltage_sensor.sch Sheet: / The design features a shunt resistor and the LTC4151 to convert

Id: 1/1 Title: Design of the shunt module

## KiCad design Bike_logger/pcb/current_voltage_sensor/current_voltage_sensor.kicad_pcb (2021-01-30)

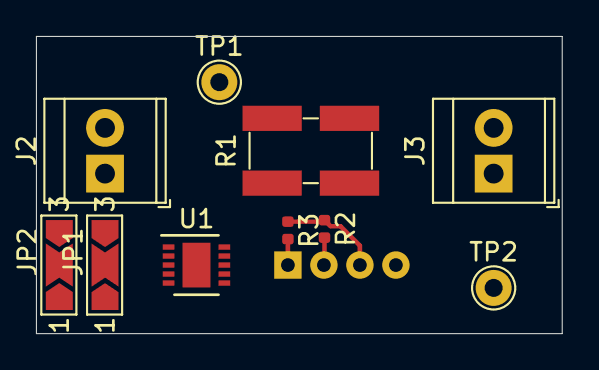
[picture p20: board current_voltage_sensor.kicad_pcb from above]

Board: 2 copper layers, 29.2 x 16.5 mm, 11 parts (1 on the bottom side), 10 nets.

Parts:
J1: Conn_01x04; NS-Tech_Grove_1x04_P2mm_Vertical
J2, J3: Conn_01x01; TerminalBlock_TE_282834-2_1x02_P2.54mm_Horizontal
JP1, JP2: SolderJumper_3_Open; SolderJumper-3_P2.0mm_Open_TrianglePad1.0x1.5mm_NumberLabels
R1: 0.02 ohm; R_Shunt_Ohmite_LVK25
R2, R3: 2K; R_0402_1005Metric
TP1, TP2: TestPoint; TestPoint_THTPad_D2.0mm_Drill1.0mm
U1: LTC4151; DFN-10-1EP_3x3mm_P0.5mm_EP1.55x2.48mm

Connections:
+3V3: J1.3, R2.1, R3.1
/ADR0: JP1.2, U1.4
/ADR1: JP2.2, U1.3
/SCL: J1.1, R3.2, U1.6
/SDA: J1.2, R2.2, U1.7
/SENSE+: J3.1, JP1.1, JP2.1, R1.2, U1.1, U1.2
/SENSE-: J2.1, R1.1, U1.10
GND: J1.4, JP1.3, JP2.3, U1.9
unnamed: TP1.1, U1.8
unnamed: TP2.1, U1.5

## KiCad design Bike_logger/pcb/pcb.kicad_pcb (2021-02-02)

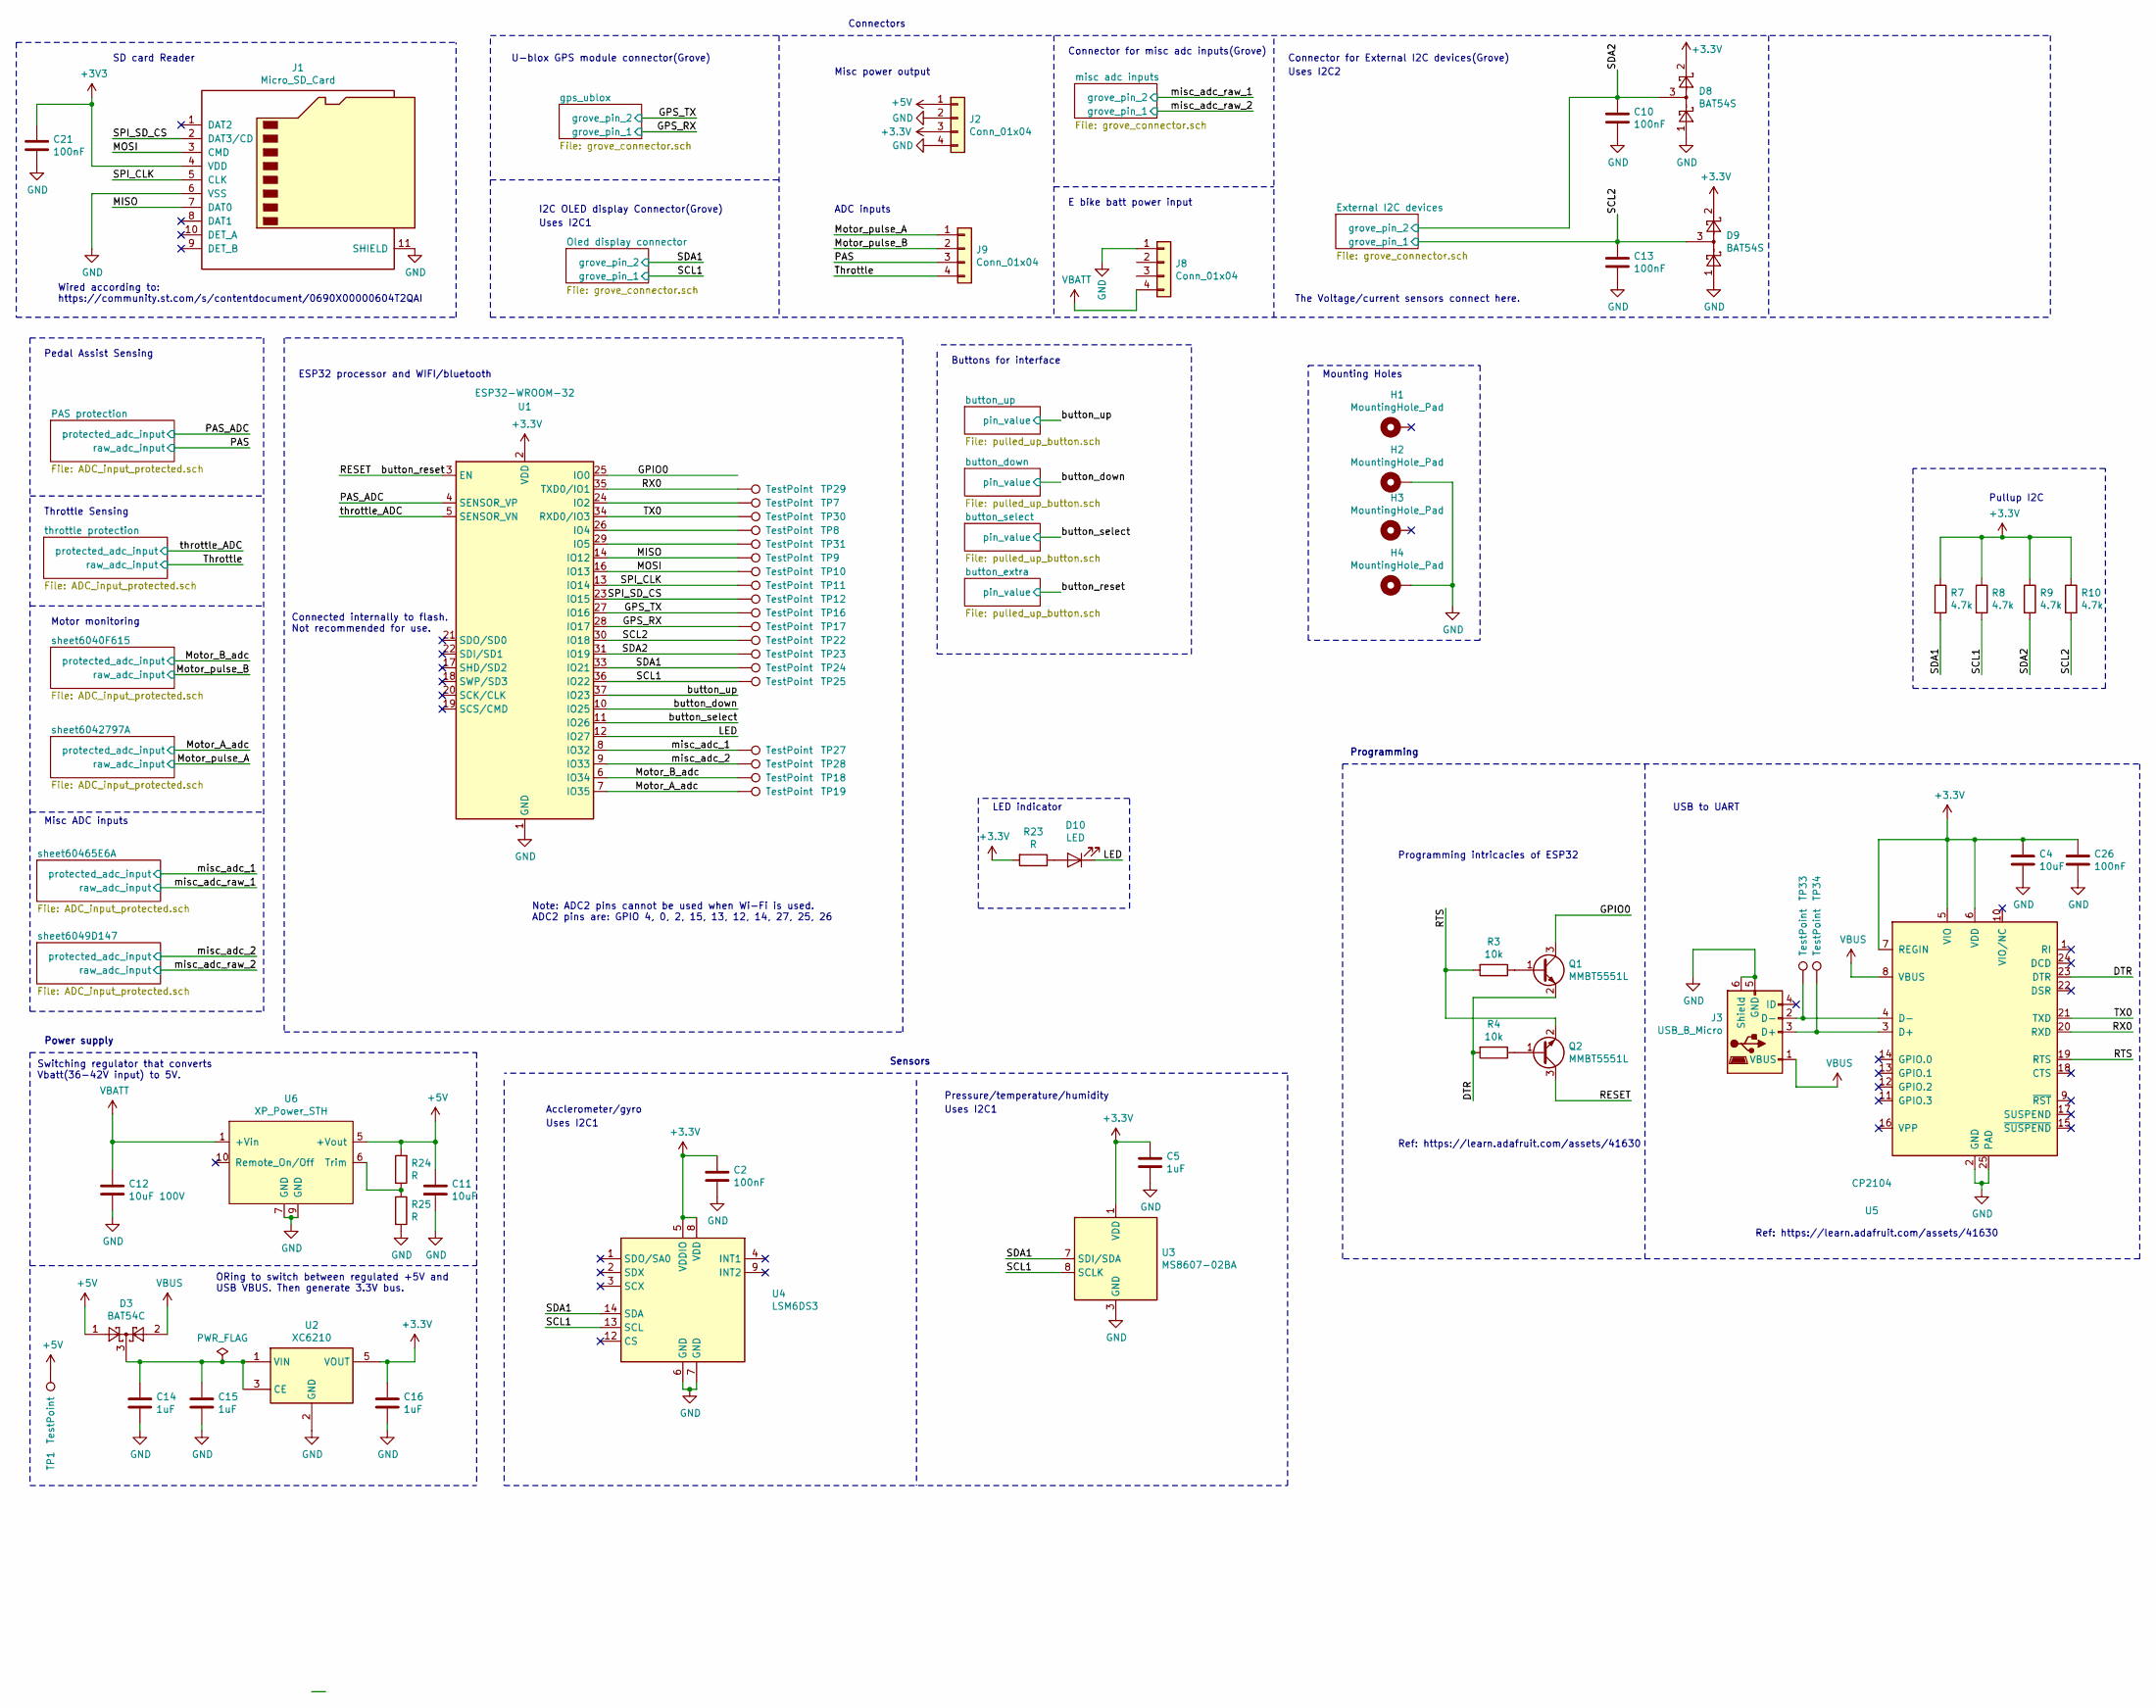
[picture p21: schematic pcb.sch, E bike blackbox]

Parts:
C2, C10, C13, C21, C26: 100nF; C_0402_1005Metric
C4, C11: 10uF; C_0603_1608Metric
C5, C14, C15, C16: 1uF; C_0603_1608Metric
C12: 10uF 100V; CP_Elec_6.3x7.7
D3: BAT54C; SOT-23
D8, D9: BAT54S; SOT-23
D10: LED; LED_0402_1005Metric
H1, H2, H3, H4: MountingHole_Pad; MountingHole_2.7mm_M2.5_custom
J1: Micro_SD_Card; microSD_HC_Hirose_DM3AT-SF-PEJM5
J2, J8, J9: Conn_01x04; TerminalBlock_Phoenix_MKDS-1,5-4-5.08_1x04_P5.08mm_Horizont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
J3: USB_B_Micro; USB_Micro-B_Molex-105017-0001
Q1, Q2: MMBT5551L; SOT-23
R3, R4: 10k; R_0402_1005Metric
R7, R8, R9, R10: 4.7k; R_0402_1005Metric
R23, R24, R25: R; R_0402_1005Metric
TP1, TP7, TP8, TP9, TP10, TP11, TP12, TP16, TP17, TP18, TP19, TP22, TP23, TP24, TP25, TP27, TP28, TP29, TP30, TP31, TP33, TP34: TestPoint; TestPoint_Pad_1.0x1.0mm
U1: ESP32-WROOM-32
U2: XC6210; SOT-23-5
U3: MS8607-02BA; LGA-8_3x5mm_P1.25mm
U4: LSM6DS3; LGA-14_3x2.5mm_P0.5mm_LayoutBorder3x4y
U5: CP2104; QFN-24-1EP_4x4mm_P0.5mm_EP2.6x2.6mm
U6: XP_Power_STH; STH0548S3V3

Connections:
+5V: C11.2, D3.1, J2.1, R24.2, TP1.1, U6.5 (+Vout)
/DTR: Q1.2 (E), R4.2, U5.23 (DTR)
/GPIO0: Q1.3 (C), U1.25 (IO0)
/GPS_RX: TP17.1, U1.28 (IO17); also elsewhere on the board
/GPS_TX: TP16.1, U1.27 (IO16); also elsewhere on the board
/LED: D10.1 (K), U1.12 (IO27)
/MISO: J1.7 (DAT0), TP9.1, U1.14 (IO12)
/MOSI: J1.3 (CMD), TP10.1, U1.16 (IO13)
/Motor_A_adc: TP19.1, U1.7 (IO35); also elsewhere on the board
/Motor_B_adc: TP18.1, U1.6 (IO34); also elsewhere on the board
/Motor_pulse_A: J9.1; also elsewhere on the board
/Motor_pulse_B: J9.2; also elsewhere on the board
/PAS: J9.3; also elsewhere on the board
/PAS_ADC: U1.4 (SENSOR_VP); also elsewhere on the board
/RESET: Q2.3 (C), U1.3 (EN); also elsewhere on the board
/RTS: Q2.2 (E), R3.2, U5.19 (RTS)
/RX0: TP29.1, U1.35 (TXD0/IO1), U5.20 (RXD)
/SCL1: R8.2, TP25.1, U1.36 (IO22), U3.8 (SCLK), U4.13 (SCL); also elsewhere on the board
/SCL2: C13.1, D9.3, R10.2, TP22.1, U1.30 (IO18); also elsewhere on the board
/SDA1: R7.2, TP24.1, U1.33 (IO21), U3.7 (SDI/SDA), U4.14 (SDA); also elsewhere on the board
/SDA2: C10.1, D8.3, R9.2, TP23.1, U1.31 (IO19); also elsewhere on the board
/SPI_CLK: J1.5 (CLK), TP11.1, U1.13 (IO14)
/SPI_SD_CS: J1.2 (DAT3/CD), TP12.1, U1.23 (IO15)
/TX0: TP30.1, U1.34 (RXD0/IO3), U5.21 (TXD)
/Throttle: J9.4; also elsewhere on the board
/button_select: U1.11 (IO26); also elsewhere on the board
/misc_adc_1: TP27.1, U1.8 (IO32); also elsewhere on the board
/misc_adc_2: TP28.1, U1.9 (IO33); also elsewhere on the board
/throttle_ADC: U1.5 (SENSOR_VN); also elsewhere on the board
GND: C2.2, C4.1, C5.2, C10.2, C11.1, C12.1, C13.2, C14.1, C15.1, C16.1, C21.2, C26.1, D8.1, D9.1, H2.1, H4.1, J1.6 (VSS), J1.11 (SHIELD), J2.2, J2.4, J3.5 (GND), J3.6 (Shield), J8.1, R25.2, U1.1 (GND), U1.15 (GND), U1.38 (GND), U2.2 (GND), U3.3 (GND), U4.6 (GND), U4.7 (GND), U5.2 (GND), U5.25 (PAD), U6.7 (GND), U6.9 (GND); also elsewhere on the board
unnamed: C14.2, C15.2, D3.3, U2.1 (VIN), U2.3 (CE)
unnamed: D10.2 (A), R23.1
unnamed: J3.2 (D-), TP33.1, U5.4 (D-)
unnamed: J3.3 (D+), TP34.1, U5.3 (D+)
unnamed: Q1.1 (B), R3.1
unnamed: Q2.1 (B), R4.1
unnamed: R24.1, R25.1, U6.6 (Trim)
unnamed: TP7.1, U1.24 (IO2)
unnamed: TP8.1, U1.26 (IO4)
unnamed: TP31.1, U1.29 (IO5)
VBATT: C12.2, J8.4, U6.1 (+Vin)
VBUS: D3.2, J3.1 (VBUS), U5.8 (VBUS)

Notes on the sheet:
Note: ADC2 pins cannot be used when Wi-Fi is used. ADC2 pins are: GPIO 4, 0, 2, 15, 13, 12, 14, 27, 25, 26
Pressure/temperature/humidity
ESP32 processor and WIFI/bluetooth
SD card Reader
USB to UART
ADC inputs
Programming intricacies of ESP32
Pedal Assist Sensing
Throttle Sensing
Wired according to: https://community.st.com/s/contentdocument/0690X00000604T2QAI
U-blox GPS module connector(Grove)
Mounting Holes
Ref: https://learn.adafruit.com/assets/41630
Buttons for interface
Connected internally to flash. Not recommended for use.
Motor monitoring
Misc ADC inputs
Connectors
Switching regulator that converts Vbatt(36-42V input) to 5V.
I2C OLED display Connector(Grove)
Connector for External I2C devices(Grove)
The Voltage/current sensors connect here.
ORing to switch between regulated +5V and USB VBUS. Then generate 3.3V bus.
LED indicator
Connector for misc adc inputs(Grove)
E bike batt power input
Pullup I2C
Uses I2C2
Uses I2C1
Misc power output
Power supply
Sensors
Acclerometer/gyro
Programming

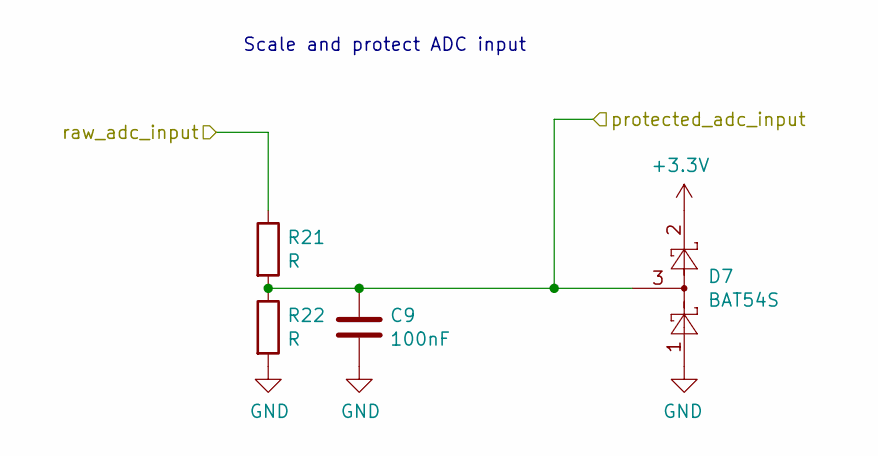
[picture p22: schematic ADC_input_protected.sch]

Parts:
C1: 100nF; C_0402_1005Metric
D1: BAT54S; SOT-23
R1, R2: R; R_0402_1005Metric

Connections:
/Throttle: R1.1; also elsewhere on the board
/throttle_ADC: C1.1, D1.3, R1.2, R2.1; also elsewhere on the board
GND: C1.2, D1.1, R2.2; also elsewhere on the board

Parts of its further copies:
C3, C6, C7, C8, C9: 100nF; C_0402_1005Metric
D2, D4, D5, D6, D7: BAT54S; SOT-23
R5, R6, R15, R16, R17, R18, R19, R20, R21, R22: R; R_0402_1005Metric

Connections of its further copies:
/Motor_A_adc: C7.1, D5.3, R17.2, R18.1; also elsewhere on the board
/Motor_B_adc: C3.1, D4.3, R15.2, R16.1; also elsewhere on the board
/Motor_pulse_A: R17.1; also elsewhere on the board
/Motor_pulse_B: R15.1; also elsewhere on the board
/PAS: R5.1; also elsewhere on the board
/PAS_ADC: C6.1, D2.3, R5.2, R6.1; also elsewhere on the board
/misc_adc_1: C8.1, D6.3, R19.2, R20.1; also elsewhere on the board
/misc_adc_2: C9.1, D7.3, R21.2, R22.1; also elsewhere on the board
/misc_adc_raw_1: R19.1; also elsewhere on the board
/misc_adc_raw_2: R21.1; also elsewhere on the board
GND: C3.2, C6.2, C7.2, C8.2, C9.2, D2.1, D4.1, D5.1, D6.1, D7.1, R6.2, R16.2, R18.2, R20.2, R22.2; also elsewhere on the board

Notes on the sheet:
Scale and protect ADC input

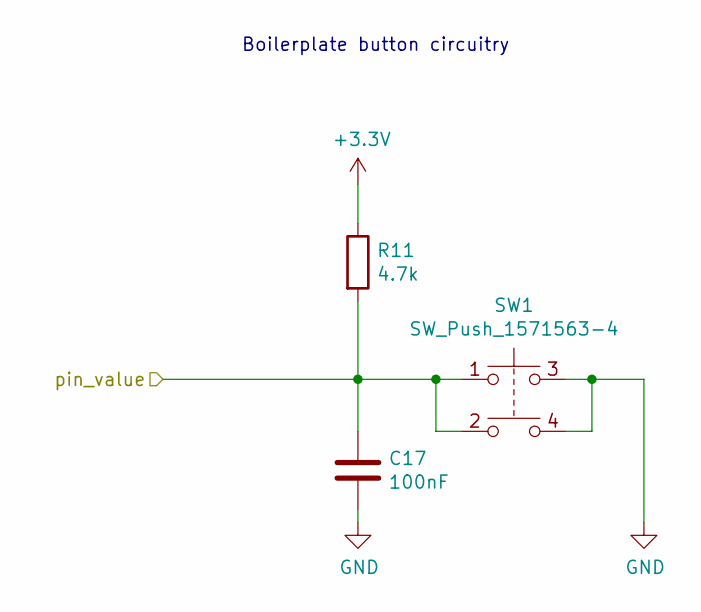
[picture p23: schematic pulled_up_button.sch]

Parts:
C18: 100nF; C_0402_1005Metric
R11: 4.7k; R_0402_1005Metric
SW1: SW_Push_1571563-4; SW_1571563-4

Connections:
GND: C18.2, SW1.3, SW1.4; also elsewhere on the board

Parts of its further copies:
C17, C19, C20: 100nF; C_0402_1005Metric
R12, R13, R14: 4.7k; R_0402_1005Metric
SW2, SW4, SW4_reset1: SW_Push_1571563-4; SW_1571563-4

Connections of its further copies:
/RESET: C20.1, R14.2, SW4_reset1.1, SW4_reset1.2; also elsewhere on the board
/button_select: C19.1, R13.2, SW4.1, SW4.2; also elsewhere on the board
GND: C17.2, C19.2, C20.2, SW2.3, SW2.4, SW4.3, SW4.4, SW4_reset1.3, SW4_reset1.4; also elsewhere on the board

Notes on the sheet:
Boilerplate button circuitry

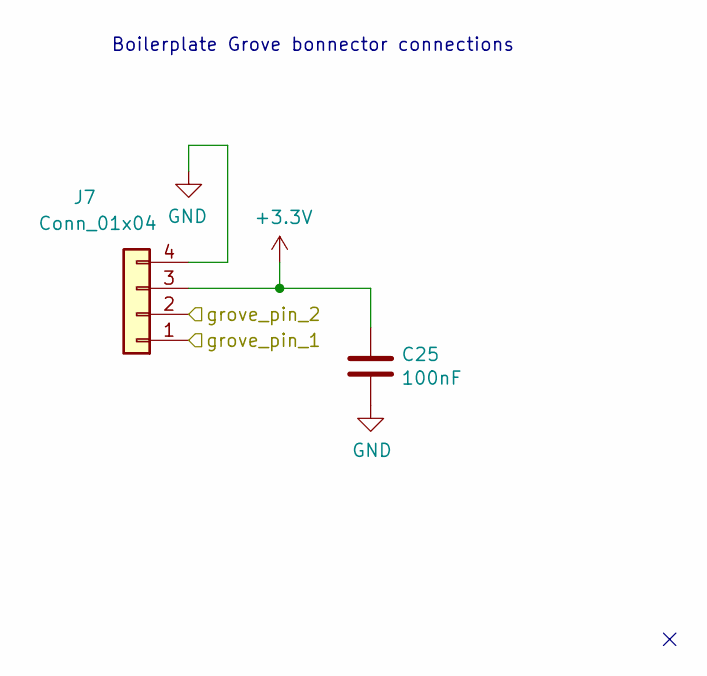
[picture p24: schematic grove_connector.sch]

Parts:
C22: 100nF; C_0402_1005Metric
J4: Conn_01x04; NS-Tech_Grove_1x04_P2mm_Vertical

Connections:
/GPS_RX: J4.1; also elsewhere on the board
/GPS_TX: J4.2; also elsewhere on the board
GND: C22.2, J4.4; also elsewhere on the board

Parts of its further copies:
C23, C24, C25: 100nF; C_0402_1005Metric
J5, J6, J7: Conn_01x04; NS-Tech_Grove_1x04_P2mm_Vertical

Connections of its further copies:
/SCL1: J5.1; also elsewhere on the board
/SCL2: J6.1; also elsewhere on the board
/SDA1: J5.2; also elsewhere on the board
/SDA2: J6.2; also elsewhere on the board
/misc_adc_raw_1: J7.2; also elsewhere on the board
/misc_adc_raw_2: J7.1; also elsewhere on the board
GND: C23.2, C24.2, C25.2, J5.4, J6.4, J7.4; also elsewhere on the board

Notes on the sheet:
Boilerplate Grove bonnector connections

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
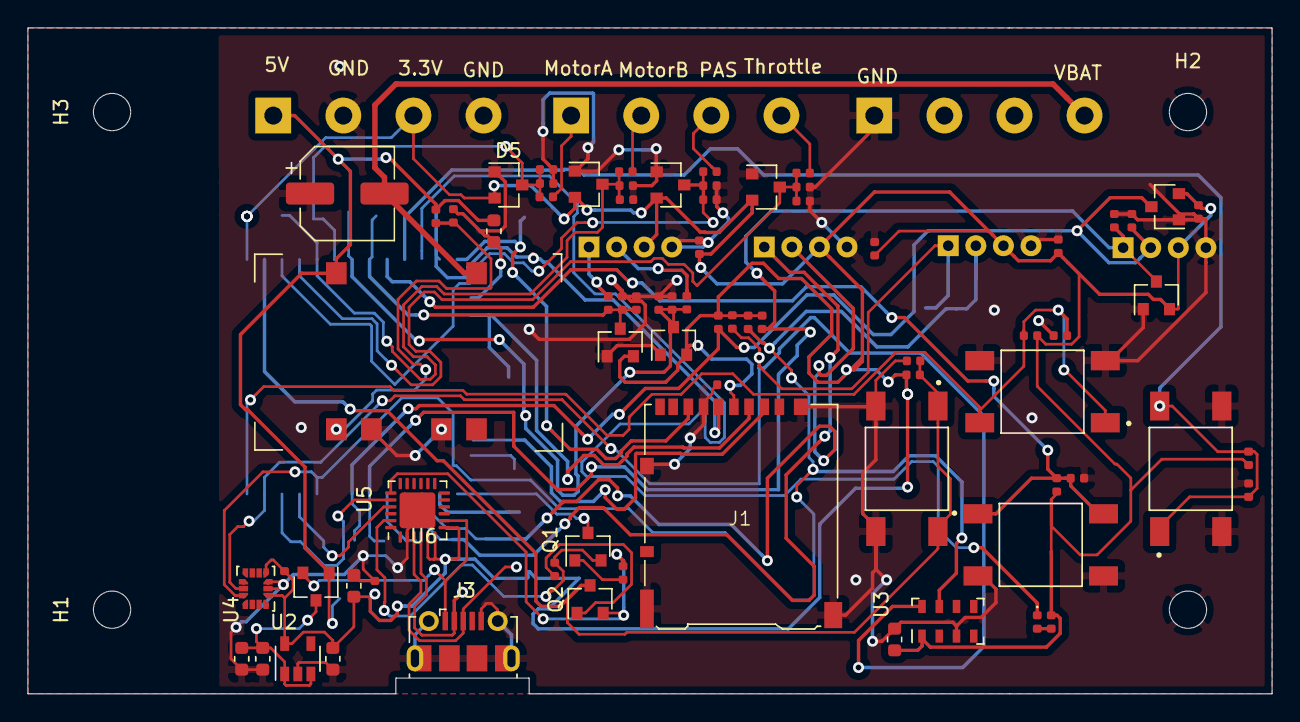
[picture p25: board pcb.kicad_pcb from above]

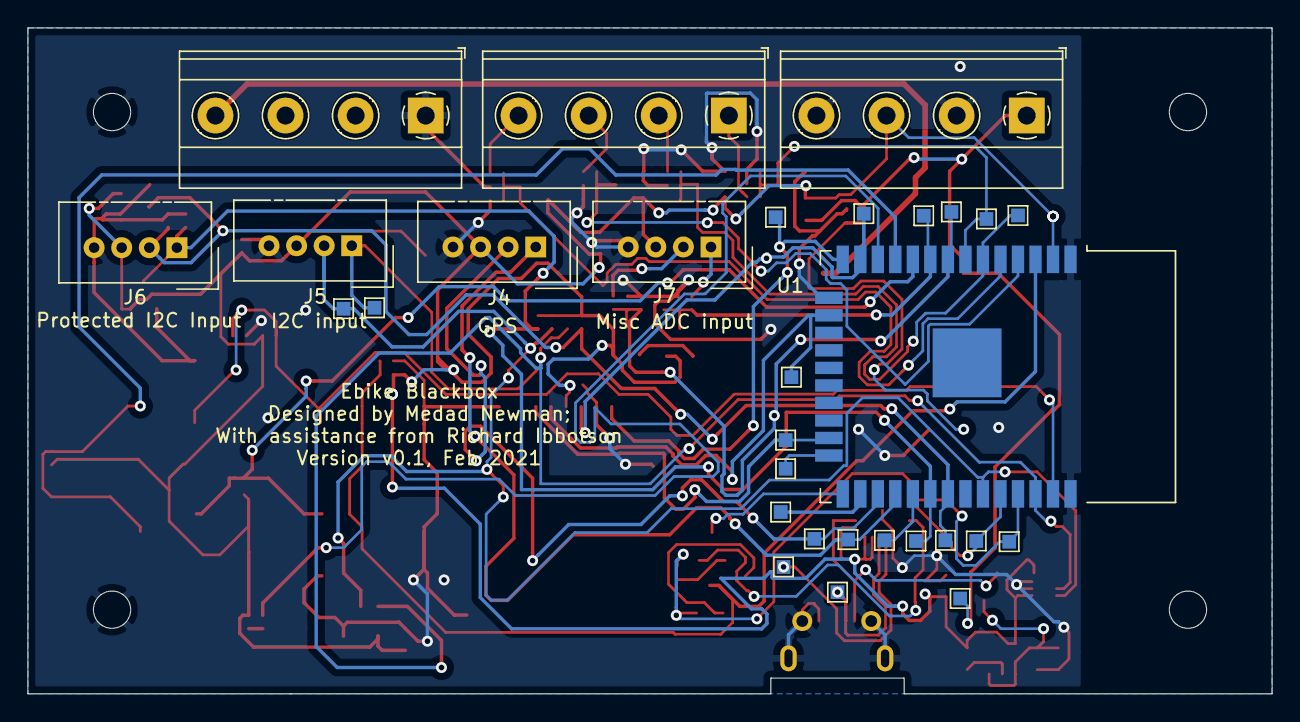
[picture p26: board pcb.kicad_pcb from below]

Board: 2 copper layers, 90.2 x 48.3 mm, 108 parts (30 on the bottom side), 47 nets.

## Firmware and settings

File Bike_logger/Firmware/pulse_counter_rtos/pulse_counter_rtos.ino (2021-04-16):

/* MCPWM basic config example

   This example code is in the Public Domain (or CC0 licensed, at your option.)

   Unless required by applicable law or agreed to in writing, this
   software is distributed on an "AS IS" BASIS, WITHOUT WARRANTIES OR
   CONDITIONS OF ANY KIND, either express or implied.
*/

/*
 * This example will show you how to use each submodule of MCPWM unit.
 * The example can't be used without modifying the code first.
 * Edit the macros at the top of mcpwm_example_basic_config.c to enable/disable the submodules which are used in the example.
 * 
 * Connect pin 21 to pin 22 to see test signal
 * Connect 5V pwm pulse to pin 39 to also see test signal
 */

#include <stdio.h>
#include "string.h"
#include "freertos/FreeRTOS.h"
#include "freertos/task.h"
#include "freertos/queue.h"
#include "esp_attr.h"
#include "soc/rtc.h"
#include "driver/mcpwm.h"
#include "soc/mcpwm_reg.h"
#include "soc/mcpwm_struct.h"

const uint32_t SERIAL_SPEED = 115200; // Use fast serial speed 2 Mbits/s

#define CAP_SIG_NUM 3   //Three capture signals

#define CAP0_INT_EN BIT(27)  //Capture 0 interrupt bit
#define CAP1_INT_EN BIT(28)  //Capture 1 interrupt bit
#define CAP2_INT_EN BIT(29)  //Capture 2 interrupt bit

#define GPIO_CAP0_IN   39   //Set GPIO 39 as  CAP0
#define GPIO_CAP1_IN   25   //Set GPIO 25 as  CAP1
#define GPIO_CAP2_IN   22   //Set GPIO 22 as  CAP2

#define LED_BUILTIN 27
#define TEST_TOGGLE_PIN_1 16
#define TEST_TOGGLE_PIN_2 21


typedef struct {
  uint32_t capture_signal;
  mcpwm_capture_signal_t sel_cap_signal;
  uint32_t edge_direction;
} capture;

typedef struct {
  uint32_t high_period;
  uint32_t low_period;
} duty_cycle_params_t;



duty_cycle_params_t dcycle_params[CAP_SIG_NUM];


xQueueHandle cap_queue;
static mcpwm_dev_t *MCPWM[2] = {&MCPWM0, &MCPWM1};

static void mcpwm_example_gpio_initialize(void)
{
    Serial.printf("initializing mcpwm gpio...\n");

    mcpwm_pin_config_t pin_config = {
        .mcpwm0a_out_num = -1,
        .mcpwm0b_out_num = -1,
        .mcpwm1a_out_num = -1,
        .mcpwm1b_out_num = -1,
        .mcpwm2a_out_num = -1,
        .mcpwm2b_out_num = -1,
        .mcpwm_sync0_in_num  = -1,
        .mcpwm_sync1_in_num  = -1,
        .mcpwm_sync2_in_num  = -1,
        .mcpwm_fault0_in_num = -1,
        .mcpwm_fault1_in_num = -1,
        .mcpwm_fault2_in_num = -1,
        .mcpwm_cap0_in_num   = GPIO_CAP0_IN,
        .mcpwm_cap1_in_num   = GPIO_CAP1_IN,
        .mcpwm_cap2_in_num   = GPIO_CAP2_IN
    };
    mcpwm_set_pin(MCPWM_UNIT_0, &pin_config);


    gpio_pullup_en((gpio_num_t)GPIO_CAP0_IN);    //Enable pull down on CAP0   signal
    gpio_pullup_en((gpio_num_t)GPIO_CAP1_IN);    //Enable pull down on CAP1   signal
    gpio_pullup_en((gpio_num_t)GPIO_CAP2_IN);    //Enable pull down on CAP2   signal
}

/**
 * @brief Set gpio 21 as our test signal that generates high-low waveform continuously, connect this gpio to capture pin.
 */
static void gpio_test_signal(void *arg)
{
    Serial.printf("intializing test signal...\n");
    gpio_config_t gp;
    gp.intr_type = GPIO_INTR_DISABLE;
    gp.mode = GPIO_MODE_OUTPUT;
    gp.pin_bit_mask = GPIO_SEL_21;
    gpio_config(&gp);
    while (1) {
        //here the period of test signal is 20ms
        gpio_set_level(GPIO_NUM_21, 1); //Set high
        vTaskDelay(pdMS_TO_TICKS(30));          //delay of 500ms
        gpio_set_level(GPIO_NUM_21, 0); //Set low
        vTaskDelay(pdMS_TO_TICKS(160));         //delay of 500ms
    }
}

static float duty_cycle(int low, int high)
{
  return (float)high / (float)(low + high);
}

static void log_signal(int index, capture evt, uint32_t *current_cap_value, uint32_t *previous_cap_value, uint32_t *edge_direction_value)
{
  current_cap_value[index] = evt.capture_signal - previous_cap_value[index];
  previous_cap_value[index] = evt.capture_signal;
  current_cap_value[index] = (current_cap_value[index] / 10000) * (10000000000 / rtc_clk_apb_freq_get());
  edge_direction_value[index] = evt.edge_direction;

  switch (evt.edge_direction)
  {
    case 1:
      dcycle_params[index].low_period = current_cap_value[index];
      break;
    case 2:
      dcycle_params[index].high_period = current_cap_value[index];
      break;
  }

  if (edge_direction_value[index] == 1) // TODO: convert this to enum: 1 = positive edge, 2 = negetive edge
  {
    float d_cycle = duty_cycle(dcycle_params[index].low_period, dcycle_params[index].high_period);
    Serial.printf("CAP%d : %d us DIRECTION : %d Duty_cycle: %f\n", index, current_cap_value[index], edge_direction_value[index], d_cycle);
  }

}

/**
 * @brief When interrupt occurs, we receive the counter value and display the time between two rising edge
 */
static void disp_captured_signal(void *arg)
{
  uint32_t *current_cap_value = (uint32_t *)malloc(CAP_SIG_NUM * sizeof(uint32_t));
  uint32_t *previous_cap_value = (uint32_t *)malloc(CAP_SIG_NUM * sizeof(uint32_t));
  uint32_t *edge_direction_value = (uint32_t *)malloc(CAP_SIG_NUM * sizeof(uint32_t));
  capture evt;
  while (1) {
    xQueueReceive(cap_queue, &evt, portMAX_DELAY);
    if (evt.sel_cap_signal == MCPWM_SELECT_CAP0) {
      log_signal(MCPWM_SELECT_CAP0, evt, current_cap_value, previous_cap_value, edge_direction_value);
    }
    if (evt.sel_cap_signal == MCPWM_SELECT_CAP1) {
      log_signal(MCPWM_SELECT_CAP1, evt, current_cap_value, previous_cap_value, edge_direction_value);
    }
    if (evt.sel_cap_signal == MCPWM_SELECT_CAP2) {
      log_signal(MCPWM_SELECT_CAP2, evt, current_cap_value, previous_cap_value, edge_direction_value);
    }
  }
}


/**
 * @brief this is ISR handler function, here we check for interrupt that triggers rising edge on CAP0 signal and according take action
 */
static void IRAM_ATTR isr_handler(void*)
{
  uint32_t mcpwm_intr_status;
  capture evt;
  mcpwm_intr_status = MCPWM[MCPWM_UNIT_0]->int_st.val; //Read interrupt status



  if (mcpwm_intr_status & CAP0_INT_EN) { //Check for interrupt on rising edge on CAP0 signal
    evt.capture_signal = mcpwm_capture_signal_get_value(MCPWM_UNIT_0, MCPWM_SELECT_CAP0); //get capture signal counter value
    evt.sel_cap_signal = MCPWM_SELECT_CAP0;
    evt.edge_direction = mcpwm_capture_signal_get_edge(MCPWM_UNIT_0, MCPWM_SELECT_CAP0);
    xQueueSendFromISR(cap_queue, &evt, NULL);
  }
  if (mcpwm_intr_status & CAP1_INT_EN) { //Check for interrupt on rising edge on CAP0 signal
    evt.capture_signal = mcpwm_capture_signal_get_value(MCPWM_UNIT_0, MCPWM_SELECT_CAP1); //get capture signal counter value
    evt.sel_cap_signal = MCPWM_SELECT_CAP1;
    evt.edge_direction = mcpwm_capture_signal_get_edge(MCPWM_UNIT_0, MCPWM_SELECT_CAP1);
    xQueueSendFromISR(cap_queue, &evt, NULL);
  }
  if (mcpwm_intr_status & CAP2_INT_EN) { //Check for interrupt on rising edge on CAP0 signal
    evt.capture_signal = mcpwm_capture_signal_get_value(MCPWM_UNIT_0, MCPWM_SELECT_CAP2); //get capture signal counter value
    evt.sel_cap_signal = MCPWM_SELECT_CAP2;
    evt.edge_direction = mcpwm_capture_signal_get_edge(MCPWM_UNIT_0, MCPWM_SELECT_CAP2);
    xQueueSendFromISR(cap_queue, &evt, NULL);
  }


  MCPWM[MCPWM_UNIT_0]->int_clr.val = mcpwm_intr_status;

}

/**
 * @brief Configure whole MCPWM module
 */
static void mcpwm_example_config(void *arg)
{
    //1. mcpwm gpio initialization
    mcpwm_example_gpio_initialize();

     //7. Capture configuration
    //comment if you don't want to use capture submodule, also u can comment the capture gpio signals
    //configure CAP0, CAP1 and CAP2 signal to start capture counter on rising edge
    //we generate a gpio_test_signal of 20ms on GPIO 12 and connect it to one of the capture signal, the disp_captured_function displays the time between rising edge
    //In general practice you can connect Capture  to external signal, measure time between rising edge or falling edge and take action accordingly
    mcpwm_capture_enable(MCPWM_UNIT_0, MCPWM_SELECT_CAP0, MCPWM_POS_EDGE, 0);  //capture signal on rising edge, prescale = 0 i.e. 800,000,000 counts is equal to one second
    mcpwm_capture_enable(MCPWM_UNIT_0, MCPWM_SELECT_CAP1, MCPWM_POS_EDGE, 0);  //capture signal on rising edge, prescale = 0 i.e. 800,000,000 counts is equal to one second
    mcpwm_capture_enable(MCPWM_UNIT_0, MCPWM_SELECT_CAP2, MCPWM_POS_EDGE, 0);  //capture signal on rising edge, prescale = 0 i.e. 800,000,000 counts is equal to one second
    
    // Enable detect on BOTH edges, not only positive edge. arduino-esp32 v1.0.6 does not have the MCPWM_BOTH_EDGE option,
    // hence setting it manually here.
    MCPWM[MCPWM_UNIT_0]->cap_cfg_ch[MCPWM_SELECT_CAP0].mode =  BIT(1)|BIT(0);
    MCPWM[MCPWM_UNIT_0]->cap_cfg_ch[MCPWM_SELECT_CAP1].mode =  BIT(1)|BIT(0);
    MCPWM[MCPWM_UNIT_0]->cap_cfg_ch[MCPWM_SELECT_CAP2].mode =  BIT(1)|BIT(0);

    
    //enable interrupt, so each this a rising edge occurs interrupt is triggered
    MCPWM[MCPWM_UNIT_0]->int_ena.val = CAP0_INT_EN | CAP1_INT_EN | CAP2_INT_EN;  //Enable interrupt on  CAP0, CAP1 and CAP2 signal
    mcpwm_isr_register(MCPWM_UNIT_0, isr_handler, NULL, ESP_INTR_FLAG_IRAM, NULL);  //Set ISR Handler


    vTaskDelete(NULL);
}

void setup(void)
{
    Serial.printf("Testing MCPWM...\n");
    Serial.begin(SERIAL_SPEED);
    cap_queue = xQueueCreate(1, sizeof(capture)); //comment if you don't want to use capture module
    xTaskCreate(disp_captured_signal, "mcpwm_config", 4096, NULL, 5, NULL);  //comment if you don't want to use capture module
    xTaskCreate(gpio_test_signal, "gpio_test_signal", 4096, NULL, 5, NULL); //comment if you don't want to use capture module
    xTaskCreate(mcpwm_example_config, "mcpwm_example_config", 4096, NULL, 5, NULL);
}


void loop()
{
  
}

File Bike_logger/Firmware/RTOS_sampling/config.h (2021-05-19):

#ifdef __cplusplus
extern "C"
{
#endif

#ifndef Config_h
#define Config_h

  /* ==================================================================== */
  /* ========================== include files =========================== */
  /* ==================================================================== */

  /* Inclusion of system and local header files goes here */

  /* ==================================================================== */
  /* ============================ constants ============================= */
  /* ==================================================================== */

  /* #define and enum statements go here */

#define LED_BUILTIN 27
#define RXD2 17
#define TXD2 16

#define INA_226_I2C_ADDRESS 0x41

/* Config section */

/*
  Set to true or false to poll/not poll
*/
#define POLL_BARO (true)
#define POLL_GPS (true)
#define POLL_IMU (true)
#define POLL_INA226 (true)
#define POLL_PAS (true)
#define POLL_MOTOR_SPEED (true)
#define POLL_BRAKE (true)

#define HEAP_ANALYSIS (false)
#define PERIODIC_CLOSE_FILE (true)
#define INTERVAL_BETWEEN_FLUSHING_FILE 10000UL

/* poll intervals in milliseconds */
#define INA226_SAMPLE_INTERVAL 10
#define GNSS_SAMPLE_INTERVAL 50
#define BARO_SAMPLE_INTERVAL 250
#define IMU_SAMPLE_INTERVAL 10
#define BLINK_INTERVAL 100
#define BRAKE_INTERVAL 100
#define SPEED_INTERVAL 100

#define MOTOR_PULSE_A_PIN 35
#define MOTOR_PULSE_B_PIN 34
#define PAS 36
#define THROTTLE 39

/* Number of GPS fixes in a second */
#define FIXS_PER_SECOND 10

/* INA226 info */
#define FULL_RANGE_VOLTAGE_DROP (float)0.08192 // Volts
//#define SHUNT_RESISTANCE (float)0.00217        // Ohms for battery measurment module
#define SHUNT_RESISTANCE (float)0.00215 // Ohms for e-bike module

/* I = V/R */
#define INA226_FULL_CURRENT_RANGE (float)(FULL_RANGE_VOLTAGE_DROP / SHUNT_RESISTANCE) // Amps

  /* ==================================================================== */
  /* ========================== public data ============================= */
  /* ==================================================================== */

  /* Definition of public (external) data types go here */

  /* ==================================================================== */
  /* ======================= public functions =========================== */
  /* ==================================================================== */

  /* Function prototypes for public (external) functions go here */

#endif
#ifdef __cplusplus
}
#endif

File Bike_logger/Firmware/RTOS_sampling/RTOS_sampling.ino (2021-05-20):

/*********************************************************************
** @source Ebike Blackbox datalogger
**
** Main code for the Ebike logger
**
** @author Copyright (C) 2021  Medad Rufus Newman
** @version v0.1
** Mutex tips from https://microcontrollerslab.com/arduino-freertos-mutex-tutorial-priority-inversion-priority-inheritance/
********************************************************************/

/* ==================================================================== */
/* ========================== include files =========================== */
/* ==================================================================== */

/* Inclusion of system and local header files goes here */
#include "ms8607.h"
#include "Wire.h"
#include "SparkFunLSM6DS3.h"
#include "sd_card_manager.h"
#include <SparkFun_u-blox_GNSS_Arduino_Library.h>
#include <INA226_WE.h>
#include "RTOS_sampling.h"

#include <ESPNtpClient.h>
#include <WiFi.h>
#include "WifiConfig.h"
#include "config.h"
#include <bitset>
#include "heap_analysis.hpp"

#include "src/pulse_counter_adc/pulse_counter_adc.hpp"
#include "src/pulse_counter_rtos/pulse_counter_rtos.hpp"
#include "src/state_logger/state_logger.hpp"

/* ==================================================================== */
/* ============================ constants ============================= */
/* ==================================================================== */

/* #define and enum statements go here */
#if CONFIG_FREERTOS_UNICORE
#define ARDUINO_RUNNING_CORE 0
#else
#define ARDUINO_RUNNING_CORE 1
#endif

/* ==================================================================== */
/* ======================== global variables ========================== */
/* ==================================================================== */

/* Global variables definitions go here */
typedef enum
{
  CHARGE = 0,
  DISCHARGE
} INA226_STATUS;
/** Structure to initialize INA226 task */
typedef struct
{
  INA226_STATUS ina226_status;
} ina226_config_t;

ina226_config_t charge_config = {.ina226_status = CHARGE};
ina226_config_t discharge_config = {.ina226_status = DISCHARGE};

static ms8607 m_ms8607;
LSM6DS3 myIMU; //Default constructor is I2C, addr 0x6B
SD_Manager sd_manager;
SFE_UBLOX_GNSS myGNSS;
INA226_WE ina226;
TwoWire I2CINA226 = TwoWire(1);

SemaphoreHandle_t I2C1_Mutex;
SemaphoreHandle_t I2C2_Mutex;
SemaphoreHandle_t SPI_SD_Mutex;

File data_file;

char buffer_gnss[400];
char buffer_imu[400];
static char sprintfBuffer[400];
char buffer1[400];
char buffer_speed[400];
char brake_buffer[400];

const uint32_t SERIAL_SPEED = 2000000; // Use fast serial speed 2 Mbits/s
const uint32_t I2C_SPEED = 400000;     // 1 Mbits/s
/* Pin numbers for the i2c ports */
const uint16_t sda1 = 21;
const uint16_t scl1 = 22;
const uint16_t sda2 = 19;
const uint16_t scl2 = 18;

TaskHandle_t Handle_gps_Task;
TaskHandle_t Handle_baroTask;
TaskHandle_t Handle_imu_Task;
TaskHandle_t Handle_ina1_Task;
TaskHandle_t Handle_ina2_Task;
TaskHandle_t Handle_blink_Task;
TaskHandle_t Handle_speed_Task;
TaskHandle_t Handle_brake_Task;

uint16_t readings_in_one_go = 8;
uint16_t bytes_in_one_reading = 12;
uint16_t bytes_to_read = bytes_in_one_reading * readings_in_one_go;
uint16_t fifo_capacity = 4095;
long lastTime = 0; //Simple local timer.

/* ==================================================================== */
/* ============================== data ================================ */
/* ==================================================================== */

/* Definition of datatypes go here */

/* ==================================================================== */
/* ==================== function prototypes =========================== */
/* ==================================================================== */

/* Function prototypes for public (external) functions go here */

/* ==================================================================== */
/* ============================ functions ============================= */
/* ==================================================================== */

void setup()
{

  Wire.begin(sda1, scl1, I2C_SPEED);      // Acclerometer/gyro/temperature/pressure/humidity sensor
  I2CINA226.begin(sda2, scl2, I2C_SPEED); // port for INA226 only

  Serial.begin(SERIAL_SPEED);
  Serial.println("=======================================================");
  Serial.println("================ Ebike BlackBox =======================");
  Serial.println("============== By Medad Rufus Newman ==================");
  Serial.println("======= with assistance from Richard Ibbotson =========");
  Serial.println("=======================================================");

  init_ntp();

  sd_manager.SD_Manager_init();
  data_file = SD.open("/data.csv", FILE_APPEND);

  init_all_sensors();
  init_mutexes();
#if POLL_MOTOR_SPEED
  init_adc_edge_detect();
#endif

#if POLL_PAS
  setup_pulse_counter();
#endif

#if POLL_BRAKE
  init_state_logger();
#endif

  start_tasks();
}

void init_mutexes()
{
  I2C1_Mutex = xSemaphoreCreateMutex();
  if (I2C1_Mutex == NULL)
  {
    Serial.println("Mutex can not be created");
  }

  I2C2_Mutex = xSemaphoreCreateMutex();
  if (I2C2_Mutex == NULL)
  {
    Serial.println("Mutex can not be created");
  }

  SPI_SD_Mutex = xSemaphoreCreateMutex();
  if (SPI_SD_Mutex == NULL)
  {
    Serial.println("Mutex can not be created");
  }
}

void start_tasks()
{
  // Now set up tasks to run independently.
  xTaskCreatePinnedToCore(
      TaskBlink, "TaskBlink" // A name just for humans
      ,
      1024 // This stack size can be checked & adjusted by reading the Stack Highwater
      ,
      NULL, 1 // Priority, with 3 (configMAX_PRIORITIES - 1) being the highest, and 0 being the lowest.
      ,
      &Handle_blink_Task, ARDUINO_RUNNING_CORE);

#if POLL_GPS
  xTaskCreatePinnedToCore(
      TaskManageGPS, "TaskManageGPS" // A name just for humans
      ,
      10000 // This stack size can be checked & adjusted by reading the Stack Highwater
      ,
      NULL, 2 // Priority, with 3 (configMAX_PRIORITIES - 1) being the highest, and 0 being the lowest.
      ,
      &Handle_gps_Task, ARDUINO_RUNNING_CORE);
#endif

#if POLL_BARO
  xTaskCreatePinnedToCore(
      TaskReadBaro, "TaskReadBaro", 10000 // Stack size
      ,
      NULL, 2 // Priority
      ,
      &Handle_baroTask, ARDUINO_RUNNING_CORE);
#endif

#if POLL_INA226
  xTaskCreatePinnedToCore(
      TaskManageINA226, "TaskManageINA226_charge", 10000 // Stack size
      ,
      &charge_config, 2 // Priority
      ,
      &Handle_ina1_Task, ARDUINO_RUNNING_CORE);
#endif

#if 0 // to poll the charger IMU226.
  xTaskCreatePinnedToCore(
      TaskManageINA226, "TaskManageINA226_discharge", 10000 // Stack size
      ,
      &discharge_config, 2 // Priority
      ,
      &Handle_ina2_Task, ARDUINO_RUNNING_CORE);
#endif
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

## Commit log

2021-01-21 put in kicad files
    [pcb.kicad_pcb, pcb.sch]
2021-01-22 clean up
    [pcb.sch]
2021-01-22 put in usb
    [pcb.sch]
2021-01-26 put in more components
    [pcb.kicad_pcb, pcb.sch]
2021-01-28 put in sth0548
    [pcb.sch]
2021-01-29 removed current and voltage sensing from main board
    [pcb.sch]
2021-01-29 put in seperate project for current and voltage sensing
    [current_voltage_sensor.kicad_pcb, current_voltage_sensor.sch]
2021-01-29 put together draft one of current voltage module
    [current_voltage_sensor.kicad_pcb, current_voltage_sensor.sch]
2021-01-29 update footprints
    [current_voltage_sensor.kicad_pcb, current_voltage_sensor.sch, pcb.kicad_pcb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]
2021-01-29 put in custom ms8607 symbol, put in test points
    [ADC_input_protected.sch, pcb.kicad_pcb, pcb.sch]
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2021-01-30 organise diagram
    [current_voltage_sensor.sch]
2021-01-30 put in new acclerometer/gyro
    [pcb.sch]
2021-01-30 completed 30/1/2021
    [ADC_input_protected.sch, current_voltage_sensor.kicad_pcb, pcb.kicad_pcb]
2021-01-30 put in i2c pullups for I2C1 and I2C2
    [pcb.sch]
2021-01-30 set test point pad and add test points for scl buses
    [pcb.sch]
2021-01-30 use much smaller test pad
    [pcb.sch]
2021-01-30 removed lsm9d. No need for magnetometr
    [pcb.sch]
2021-01-30 use HSPI for TF card instead of VSPI; create buttons
    [ADC_input_protected.sch, pcb.sch, pulled_up_button.sch]
2021-01-30 put in buttons and adc misc pins
    [ADC_input_protected.sch, pcb.kicad_pcb, pcb.sch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]
2021-01-30 remove stray test point
    [pcb.sch]
2021-01-30 rearranged everythign
    [ADC_input_protected.sch, pcb.sch]
2021-01-30 put in switch
    [ADC_input_protected.sch, pcb.kicad_pcb, pulled_up_button.sch]
2021-01-30 sort out micro sd card
    [pcb.sch]
2021-01-30 put debouncing cap for buttons
    [pcb.sch, pulled_up_button.sch]
2021-01-30 make gps use grove connector
    [pcb.sch]
2021-01-30 put test point for 5V
    [pcb.sch]
2021-02-01 Add update from Richard
    - add 100nF decoupling at SD Card socket
    - add 100nF decoupling at GPS connector
    - Add second grove connector with misc_adc raw_ 1 and 2 on it
    - add decoupling for the external bus connectors
    - remove the ADC pins from the generic connector as now on grove. add a couple of grounds and 3.3V pin to connector so you can make useful connections. 5V might be useful too.
    - C12 will need to be 100V working and will be physically larger because of this.
    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
    [ADC_input_protected.sch, grove_connector.sch, pcb.sch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]
2021-02-01 Add update from Richard
    - caps on sensors can be 100nF
    - add 100nF decoupling in parallel with C4
    - add one LED.
    - Add pads for the trim resistors to the STH0548 regulator. Then you have some control over which supply takes priority.
    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
    [ADC_input_protected.sch, grove_connector.sch, pcb.sch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]
2021-02-01 connect LED to 3.3V. removed test points for buttons
    [pcb.sch]
2021-02-01 put in power input for batt
    [pcb.sch]
2021-02-01 update name of device
    [pcb.sch]
2021-02-01 design pcb
    [ADC_input_protected.sch, grove_connector.sch, pcb.sch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]
2021-02-01 starting to route board
    [ADC_input_protected.sch, grove_connector.sch, pcb.kicad_pcb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]
2021-02-01 use aluminum smd cap for high voltage input
    [pcb.sch]
2021-02-01 arrange pcb
    [ADC_input_protected.sch, grove_connector.sch, pcb.kicad_pcb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]
2021-02-01 put in flood of gnd
    [grove_connector.sch, pcb.kicad_pcb, pulled_up_button.sch]
2021-02-01 fix connection on protction diodes
    [ADC_input_protected.sch, grove_connector.sch, pcb.kicad_pcb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]
2021-02-01 fix error in connection to protection diode
    [pcb.sch]
2021-02-01 everything now fits within the PCB
    [ADC_input_protected.sch, grove_connector.sch, pcb.kicad_pcb]
2021-02-01 move the protection diodes
    [pcb.kicad_pcb]
2021-02-01 continue to route
    [pcb.kicad_pcb]
2021-02-01 routed stuff
    [ADC_input_protected.sch, grove_connector.sch, pcb.kicad_pcb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]
2021-02-01 more routing done
    [pcb.kicad_pcb]
2021-02-01 more routing
    [pcb.kicad_pcb]
2021-02-01 solved all drc errors
    [pcb.kicad_pcb]
2021-02-01 aligned hole
    [grove_connector.sch, pcb.kicad_pcb, pcb.sch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]
2021-02-01 dont connect the 2 mounting holes to gnd
    [grove_connector.sch, pcb.kicad_pcb, pcb.sch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]
2021-02-01 put in cut for usb slot
    [pcb.kicad_pcb]
2021-02-01 silk screen updated.
    [pcb.kicad_pcb]
2021-02-01 clean up silk screen
    [ADC_input_protected.sch, grove_connector.sch, pcb.kicad_pcb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]
2021-02-01 ready to go
    [ADC_input_protected.sch, pcb.kicad_pcb, pcb.sch]
2021-02-04 update comments on the schematic to make clearer
    [ADC_input_protected.sch, grove_connector.sch, pulled_up_button.sch]
2021-02-08 update purchase links
    [ADC_input_protected.sch, grove_connector.sch, pcb.sch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]
2021-02-16 update link of terminal bloxks
    [pcb.sch]
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2021-02-22 cosmetic changes; Added in headings
    [pcb.sch]
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2021-02-23 create simple test to write to SD with baro and IMU, at different rates
2021-02-24 use correct length vtask delay
    [ms8607.cpp]
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2021-02-26 fix printouts of data
    [RTOS_sampling.ino]
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2021-02-27 use better library for INA226. Prevents kernel panic
    [RTOS_sampling.ino]
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2021-02-27 increase stack size for imu task to prevent heap fragmentaiton
    [RTOS_sampling.ino]
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2021-02-27 use odd intervals for i2c polling to prevent clash
    [RTOS_sampling.ino]
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2021-02-27 set correct sample intervals
    [RTOS_sampling.ino]
2021-02-27 Disable barometer for now. It causes a lot of issues with memory corruption
    [RTOS_sampling.ino]
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2021-02-27 fix printout of INA226
    [RTOS_sampling.ino]
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2021-03-01 return back to using delay in ms8607 lib.
    The delay implementation is non blocking. See https://github.com/espressif/arduino-esp32/blob/3fe7c2e8cdcc34af0f5d3c55f8b4cb79ef5318cf/cores/esp32/esp32-hal-misc.c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
2021-03-01 [doesn't work yet] pass ina226 role into task
    For some reason, only one role is executing, even when the one that is not executing is higher priority
    [RTOS_sampling.ino]
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2021-03-01 Revert "print role"
    This reverts commit cc2faa3f6195c777c2676d245200a3695187ba7b.
    [RTOS_sampling.ino]
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2021-03-01 reduce stack size for TaskManageINA226.
    It is taking too much stack that other tasks cannot run.
    [RTOS_sampling.ino]
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2021-03-01 fix error in variable name
    [RTOS_sampling.ino]
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2021-03-01 set correct mutex on I2C1 for reading barometer
    [RTOS_sampling.ino]
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2021-03-06 blazing fast read, but errors are still present
    [LSM6D_FifoExample.ino]
2021-03-06 fewer errors now, completes under 1s
    [LSM6D_FifoExample.ino]
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2021-03-12 set correct constants for shunt
    [INA226_example.ino]
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2021-03-13 set correct full current range
    [RTOS_sampling.ino, config.h]
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2021-03-15 factory reset gps at init
    [RTOS_sampling.ino]
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2021-03-15 dont freeze if we don't have connection; try factory reset
    [ublox_CallbackExample1_NAV_PVT.ino]
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2021-03-16 delay after reset to allow gps to reset
    [RTOS_sampling.ino]
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2021-03-16 give ms8607 2 milliseconds more to convert
    It has had issues converting in 1 ms when using lowest resolution. So to be sure, Increase it.
    [ms8607.cpp]
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2021-04-05 fix print function
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2021-04-05 use correct input for isr
    [pulse_counter_rtos.ino]
2021-04-05 fix gpio pins for blinky
    [pulse_counter_rtos.ino]
2021-04-05 set correct input pins for capture
    [pulse_counter_rtos.ino]
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2021-04-06 fix bug in duty cycle calculations
    [pulse_counter_rtos.ino]
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2021-04-06 use fixed value to specify resolution of PWM signal output for test LED
    [pulse_counter_rtos.ino]
2021-04-06 set correct pull for buttons
    [pulse_counter_rtos.ino]
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2021-04-08 revert removing all the config instructions
    [pulse_counter_rtos.ino]
2021-04-08 set correct pin
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2021-04-15 set correct simulator speed
    [mcpwm_basic_config_example.c]
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2021-04-15 remove space in folder path Bike Logger
    This is to ensure esp-idf can handle the path. Or it throws errors. Anyway, it is not good practice to put in spaces in filepaths.
    [ADC_input_protected.sch, current_voltage_sensor.kicad_pcb, current_voltage_sensor.sch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]
2021-04-15 remove debug options no longer used
    [mcpwm_basic_config_example.c]
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2021-04-16 put in photos of noise in motor speed sense line
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2021-04-17 integrate i2s signal sampler[lpf does not work yet]
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2021-04-19 set correct pins for adc inputs PAS and brake
    [pulse_counter_rtos.cpp]
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2021-04-19 init all sensors before inititing mutexes.
    Or it seems to get stuck
    [RTOS_sampling.ino]
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2021-04-27 filter out all zero pulse delays to prevent division errors
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2021-05-06 add in plots showing brake noise
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2021-05-07 don't initialise second brake reader
    It is causing all kinds of failures. Like these:
    ```
    E (275) I2S: /home/runner/work/esp32-arduino-lib-builder/esp32-arduino-lib-builder/esp-idf/components/driver/i2s.c:897 (i2s_param_config):I2S ADC built-in only support on I2S0
    E (276) I2S: I2S param configure error
    E (276) I2S: /home/runner/work/esp32-arduino-lib-builder/esp32-arduino-lib-builder/esp-idf/components/driver/i2s.c:1251 (i2s_adc_enable):Not initialized yet
    Guru Meditation Error: Core 0 panic'ed (LoadProhibited). Exception was unhandled.
    Core 0 register dump:
    PC : 0x4013e615 PS : 0x00060f30 A0 : 0x800d0c89 A1 : 0x3ffd5460
    A2 : 0x00000001 A3 : 0x3ffd549e A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
    [pulse_counter_adc.cpp]
2021-05-07 Revert "remove repeat definitions"
    This reverts commit 196865dab4c805e0bd502ea4917cce2fe32628f4.
    [pulse_counter_adc.cpp]
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2021-05-10 revert back to old speed adc measurments
    [pulse_counter_adc.cpp]
2021-05-10 reject a bit more noise
    Done not fix the problem though. There is random noise on the line
    [state_logger.cpp]
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2021-05-10 don't reset the GPS, it takes too long to get a fix.
    [RTOS_sampling.ino]
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2021-05-10 fix brake check intervals
    [state_logger.cpp]
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2021-05-18 Log accuracies of GPS fix
    [RTOS_sampling.ino]
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
